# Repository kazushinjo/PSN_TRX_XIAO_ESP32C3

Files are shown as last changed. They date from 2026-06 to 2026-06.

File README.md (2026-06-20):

# PSN_TRX_XIAO_ESP32C3

Arduino Nano R4 + Seeed Studio XIAO ESP32C3 + Si5351 を使用した PSN 方式 SSB トランシーバー（KiCad 10.0）。

## 概要

50MHz 帯 PSN（位相シフト網）方式 SSB トランシーバー。VXO（水晶発振器）を
Si5351A クロックジェネレーターによる VFO に置き換え、Arduino Nano R4 でデジタル制御する。

Si5351 の CLK0（0°）/ CLK1（90°）二相出力を直接バランスドモジュレーターへ供給することで、
従来の RF PSN（LC 位相シフト回路）も不要となる。

## 主な仕様

| 項目 | 内容 |
|---|---|
| 周波数範囲 | 50.000 〜 51.000 MHz（6m バンド） |
| CLK0 出力 | 0° キャリア → C21（バランスドモジュレーター） |
| CLK1 出力 | 90° キャリア → C22（バランスドモジュレーター） |
| チューニングステップ | 10Hz / 100Hz / 1kHz / 10kHz / 100kHz |
| 表示 | OLED SSD1306 128×64 |
| 周波数記憶 | NVS（電源 OFF 後も保持） |

## ハードウェア構成

```
Arduino Nano R4
├── Seeed Studio XIAO ESP32C3 ─ サブコントローラ
├── Si5351A モジュール (AE-Si5351A) ─ I2C クロックジェネレーター
│   ├── CLK0（0°）  → バランスドモジュレーター C21
│   └── CLK1（90°） → バランスドモジュレーター C22
└── OLED / ロータリーエンコーダ 等

1W PA: RD06HVF1 (N-ch RF MOSFET) @ 12V, Class AB
```

## 1W パワーアンプ（Q8）

前段（2SC1815 等）の出力（約 20〜30mW）を増幅する終段アンプ。

| 項目 | 内容 |
|---|---|
| トランジスタ | **RD06HVF1**（三菱電機 N-ch RF MOSFET, 175MHz, 6W, TO-220F） |
| 電源電圧 | 12V |
| 動作クラス | Class AB |
| 静止電流 Idq | 200〜400mA（VR3 で調整） |
| 出力 | 約 1W @50MHz |
| 出力 LPF | 56pF → 270nH → 56pF（カットオフ約 60MHz） |

### バイアス回路

```
VCC(12V) → R22(470Ω) ─┬─ VR3(500Ω) → GND
                       │    ↓（ワイパー）
                       └── R21(10Ω) → Q8ゲート
```

- VR3 を中間位置でゲート電圧 ≈ **3.1V** → RD06HVF1 の Class AB 動作に最適
- VR3 を徐々に回してドレイン電流 (Idq) 200〜400mA に合わせる
- D3, D4（旧バイアスダイオード）は **0R ショート**（MOSFET では不要）
- R20（旧エミッタ抵抗 10Ω）は **0R ショート**（ソース直結 GND）

詳細は `docs/PSN_TRX_VFO改造仕様書.docx` を参照。

## KiCad ライブラリ状態

| ファイル | 状態 |
|---|---|
| `kicad/PSN_TRX.pretty/` | 全12フットプリント KiCad 10 形式 ✅ |
| `kicad/PSN_TRX.kicad_sym` | カスタムシンボル（RD06HVF1 含む）✅ |
| `kicad/fp-lib-table` | PSN_TRX ライブラリ登録済み ✅ |
| DRC ライブラリエラー | **0件** ✅ |

## ファイル構成

```
kicad/
  PSN_TRX.kicad_sch       - 回路図
  PSN_TRX.kicad_pcb       - PCB レイアウト（配線作業中）
  PSN_TRX.kicad_sym       - カスタムシンボルライブラリ
  PSN_TRX.pretty/         - カスタムフットプリントライブラリ（12点）
  BOM.md                  - 部品表（Markdown）
  bom.csv                 - 部品表（Shift-JIS CSV・入手先情報付き）
docs/
  PSN_TRX_VFO改造仕様書.docx  - 改造仕様書（部品リスト・回路図含む）
```

## 変更履歴

| 日付 | 変更内容 |
|---|---|
| 2026-06-20 | KiCad 回路図から bom.csv を新規生成（Shift-JIS）、入手先情報（秋月電子・サトー電気等）追加 |
| 2026-06-17 | Q3: 3SK59(TO-72 THT) → BF998(SOT-143 SMD)、カスタムシンボル・FP追加 |
| 2026-06-17 | Q8: 2SC1971 → RD06HVF1 (RF MOSFET) 換装、バイアス回路変更 |
| 2026-06-17 | KiCad 10 フットプリントライブラリ全面更新（12ファイル） |
| 2026-06-17 | U2: DIP-12 → DIP-8 フットプリント修正（AE-Si5351A 実寸合わせ） |

## ライセンス

MIT License

## 作者

JA3 (kazushinjo)

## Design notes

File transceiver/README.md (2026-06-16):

# PSN_TRX

PSN（位相シフト網）方式 SSB トランシーバの回路図プロジェクト（KiCad 10.0）。
50MHz 帯・VXO 制御。`PSN_TRX.kicad_sch` を手作業で作図中。

- リポジトリ: `kazushinjo/PSN_TRX_New`（Private）
- ローカル作業: `C:\Users\shinjo\OneDrive\デスクトップ\KiCad\PSN_TRX`

> ⚠️ **作業中** — まだ若干の回路追加が予定されています。追加完了後に続きの作業を進めます。

---

## リポジトリ構成

```
PSN_TRX/
├── PSN_TRX.kicad_sch          回路図本体
├── PSN_TRX.kicad_pro          プロジェクト設定
├── PSN_TRX.pretty/            自作フットプリント
│   ├── C_Trimmer_TMCV01.kicad_mod
│   ├── Transformer_ST71_CB19.kicad_mod
│   └── L_AL0510-153K_Vertical.kicad_mod
├── fp-lib-table               フットプリントライブラリ登録（${KIPRJMOD}/PSN_TRX.pretty）
├── *.py                       回路図生成・編集スクリプト（下記）
└── README.md
```

`*.kicad_prl` / `*.bak` / `*.lck` / `.history/` / `PSN_TRX-backups/` は `.gitignore` で除外。

---

## 主要コンポーネント（概算）

| 種別 | シンボル | 数 |
|---|---|---|
| 固定抵抗 | `Device:R` | 40 |
| 可変抵抗・ポット | `Device:R_Potentiometer` | 5 |
| コンデンサ | `Device:C` | 55 |
| トリマコンデンサ | `Device:C_Variable`（TC1, TC2） | 2 |
| ダイオード（1N60 ゲルマ検波） | `Device:D` | 6 |
| LED | `Device:LED` | 2 |
| トランス（7T50 等） | `Device:Transformer_1P_1S` | 9 |
| トランス（ST-71, CT付） | `Device:Transformer_1P_SS`（T1） | 1 |
| インダクタ | `Device:L`（L8 ほか） | — |
| トランジスタ | `Transistor_*` / `Device:Q_*` | 16 |
| OPアンプ | `Amplifier_Operational:LM2904`（NJM2904） | — |
| 水晶 | `Device:Crystal` | 1 |
| 三端子レギュレータ | `Regulator_Linear:MC78L05_TO92` | 1 |
| スイッチ | `Switch:SW_SPDT` / `SW_SPST` | 3 |

主要ブロックに「AF PSN・信号分割」セクション（ST-71 トランス T1 ＋ NJM2904 による音声位相分割）あり。

---

## フットプリント割り当て状況

### 割り当て済み ✅

| 部品 | フットプリント | 備考 |
|---|---|---|
| TC1 / TC2（トリマC 40p/5p） | `PSN_TRX:C_Trimmer_TMCV01` | Topmay TMCV01 |
| T1（ST-71 音声トランス） | `PSN_TRX:Transformer_ST71_CB19` | 山水 ST-71・CB-19 **リード型**・二次CT |
| L8（15mH インダクタ） | `PSN_TRX:L_AL0510-153K_Vertical` | AL0510-153K・**縦実装** |
| 固定抵抗 40個 | `Resistor_THT:R_Axial_DIN0207_L6.3mm_D2.5mm_P2.54mm_Vertical` | 1/4W・**縦実装** |
| ダイオード 6個（1N60） | `Diode_THT:D_DO-35_SOD27_P2.54mm_Vertical_CathodeUp` | DO-35・**縦実装** |

### 未割り当て ⏳
コンデンサ（55）／可変抵抗・ポット（5）／LED（2）／7T50系トランス（9）／トランジスタ（16）／OPアンプ／水晶／レギュレータ／スイッチ（3）

---

## 自作フットプリント（`PSN_TRX.pretty/`）

| 名称 | 内容 |
|---|---|
| `C_Trimmer_TMCV01` | Topmay TMCV01 セラミックトリマC（本体6×6mm, ピッチ5mm, ドリル1.2mm） |
| `Transformer_ST71_CB19` | 山水 ST-71（CB-19リード型）。pad 1,2=一次／3,4,5=二次（4=CT）。ピッチ I=8/G=14, 行間 C=16.5mm |
| `L_AL0510-153K_Vertical` | AL0510-153K 軸形インダクタ縦実装。本体D5×L14mm, リードピッチ P=2.54mm |

抵抗・ダイオードは KiCad 標準ライブラリ（`Resistor_THT` / `Diode_THT`、global fp-lib-table 登録済）を参照。

---

## スクリプト

| ファイル | 役割 |
|---|---|
| `generate_schematic.py` / `_v2.py` | 元 JPG 回路図からの初期生成（絶対座標配置） |
| `add_connections.py` / `add_wiring.py` | 配線追加 |
| `add_c13_c14.py` / `add_l4_l5.py` / `add_tc1_tc2.py` | 個別部品の追加 |
| `add_st71.py` | L8→T1 変換（reference/value/センタータップシンボル/FP 割当） |
| `set_vertical_footprints.py` | Device:R / Device:D へ縦実装FPを一括割当 |

> スクリプトは `.kicad_sch` を直接書き換えます。**実行前に KiCad を閉じる**こと。実行後は KiCad で開き直して確認。

---

## 残作業 / TODO

- [ ] 残りの回路を追加（予定）
- [ ] 未割り当て部品のフットプリント設定（C / 可変抵抗 / LED / 7T50トランス / トランジスタ / OPアンプ / 水晶 / レギュレータ / SW）
- [ ] ダイオードの向き（現状 CathodeUp）を回路に合わせて個別確認
- [ ] 抵抗サイズ（1/4W 前提）で 1/8W・1/2W があれば個別差し替え
- [ ] ERC / アノテーションの整理
- [ ] PCB レイアウト着手

---

## 環境・注意

- KiCad 10.0 / Windows 11
- ローカルが **OneDrive 配下**のため、git 同期と OneDrive 同期の競合（`.git` 内ロック等）に注意
- 配線は手動で実施

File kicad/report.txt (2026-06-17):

情報: シンボル 'L1:PSN_TRX:L_FCZ07S_CT' を処理中です。
情報: シンボル 'C1:Capacitor_THT:C_Disc_D5.0mm_W2.5mm_P2.50mm' を処理中です。
情報: シンボル 'C2:Capacitor_THT:C_Disc_D5.0mm_W2.5mm_P2.50mm' を処理中です。
情報: シンボル 'C3:Capacitor_THT:C_Disc_D5.0mm_W2.5mm_P2.50mm' を処理中です。
情報: シンボル 'C4:Capacitor_THT:C_Disc_D5.0mm_W2.5mm_P2.50mm' を処理中です。
情報: シンボル 'C5:Capacitor_THT:C_Disc_D5.0mm_W2.5mm_P2.50mm' を処理中です。
情報: シンボル 'C6:Capacitor_THT:C_Disc_D3.0mm_W1.6mm_P2.50mm' を処理中です。
情報: シンボル 'C7:Capacitor_THT:C_Disc_D5.0mm_W2.5mm_P2.50mm' を処理中です。
情報: シンボル 'C8:Capacitor_THT:C_Disc_D5.0mm_W2.5mm_P2.50mm' を処理中です。
情報: シンボル 'C9:Capacitor_THT:C_Disc_D5.0mm_W2.5mm_P2.50mm' を処理中です。
情報: シンボル 'C10:Capacitor_THT:C_Disc_D5.0mm_W2.5mm_P2.50mm' を処理中です。
情報: シンボル 'C11:Capacitor_THT:CP_Radial_D6.3mm_P2.50mm' を処理中です。
情報: シンボル 'C12:Capacitor_THT:C_Disc_D3.0mm_W1.6mm_P2.50mm' を処理中です。
情報: シンボル 'C13:Capacitor_THT:C_Disc_D5.0mm_W2.5mm_P2.50mm' を処理中です。
情報: シンボル 'C14:Capacitor_THT:C_Disc_D5.0mm_W2.5mm_P2.50mm' を処理中です。
情報: シンボル 'C15:Capacitor_THT:C_Disc_D5.0mm_W2.5mm_P2.50mm' を処理中です。
情報: シンボル 'C16:Capacitor_THT:CP_Radial_D6.3mm_P2.50mm' を処理中です。
情報: シンボル 'C17:Capacitor_THT:CP_Radial_D5.0mm_P2.00mm' を処理中です。
情報: シンボル 'C18:Capacitor_THT:CP_Radial_D5.0mm_P2.00mm' を処理中です。
情報: シンボル 'C19:Capacitor_THT:CP_Radial_D5.0mm_P2.00mm' を処理中です。
情報: シンボル 'C20:Capacitor_THT:CP_Radial_D5.0mm_P2.00mm' を処理中です。
情報: シンボル 'C21:Capacitor_THT:C_Disc_D5.0mm_W2.5mm_P2.50mm' を処理中です。
情報: シンボル 'C22:Capacitor_THT:C_Disc_D3.0mm_W1.6mm_P2.50mm' を処理中です。
情報: シンボル 'C23:Capacitor_THT:C_Disc_D5.0mm_W2.5mm_P2.50mm' を処理中です。
情報: シンボル 'C24:Capacitor_THT:C_Disc_D5.0mm_W2.5mm_P2.50mm' を処理中です。
情報: シンボル 'C25:Capacitor_THT:C_Disc_D5.0mm_W2.5mm_P2.50mm' を処理中です。
情報: シンボル 'C26:Capacitor_THT:C_Disc_D5.0mm_W2.5mm_P5.00mm' を処理中です。
情報: シンボル 'C27:Capacitor_THT:C_Disc_D5.0mm_W2.5mm_P5.00mm' を処理中です。
情報: シンボル 'C28:Capacitor_THT:C_Disc_D5.0mm_W2.5mm_P5.00mm' を処理中です。
情報: シンボル 'C29:Capacitor_THT:C_Disc_D5.0mm_W2.5mm_P5.00mm' を処理中です。
情報: シンボル 'C30:Capacitor_THT:C_Disc_D3.0mm_W1.6mm_P2.50mm' を処理中です。
情報: シンボル 'C31:Capacitor_THT:C_Disc_D5.0mm_W2.5mm_P5.00mm' を処理中です。
情報: シンボル 'C32:Capacitor_THT:C_Disc_D5.0mm_W2.5mm_P2.50mm' を処理中です。
情報: シンボル 'C33:Capacitor_THT:C_Disc_D5.0mm_W2.5mm_P2.50mm' を処理中です。
情報: シンボル 'C34:Capacitor_THT:C_Disc_D3.0mm_W1.6mm_P2.50mm' を処理中です。
情報: シンボル 'C35:Capacitor_THT:C_Disc_D5.0mm_W2.5mm_P2.50mm' を処理中です。
情報: シンボル 'C36:Capacitor_THT:C_Disc_D5.0mm_W2.5mm_P2.50mm' を処理中です。
情報: シンボル 'C37:Capacitor_THT:C_Disc_D3.0mm_W1.6mm_P2.50mm' を処理中です。
情報: シンボル 'C38:Capacitor_THT:C_Disc_D5.0mm_W2.5mm_P2.50mm' を処理中です。
情報: シンボル 'C39:Capacitor_THT:C_Disc_D5.0mm_W2.5mm_P2.50mm' を処理中です。
情報: シンボル 'C40:Capacitor_THT:C_Disc_D5.0mm_W2.5mm_P2.50mm' を処理中です。
情報: シンボル 'C41:Capacitor_THT:C_Disc_D5.0mm_W2.5mm_P2.50mm' を処理中です。
情報: シンボル 'C42:Capacitor_THT:C_Disc_D5.0mm_W2.5mm_P2.50mm' を処理中です。
情報: シンボル 'C43:Capacitor_THT:C_Disc_D3.0mm_W1.6mm_P2.50mm' を処理中です。
情報: シンボル 'C44:Capacitor_THT:C_Disc_D5.0mm_W2.5mm_P2.50mm' を処理中です。
情報: シンボル 'C45:Capacitor_THT:C_Disc_D5.0mm_W2.5mm_P2.50mm' を処理中です。
情報: シンボル 'C46:Capacitor_THT:C_Disc_D5.0mm_W2.5mm_P2.50mm' を処理中です。
情報: シンボル 'C47:Capacitor_THT:C_Disc_D5.0mm_W2.5mm_P2.50mm' を処理中です。
情報: シンボル 'C48:Capacitor_THT:C_Disc_D5.0mm_W2.5mm_P2.50mm' を処理中です。
情報: シンボル 'C49:Capacitor_THT:C_Disc_D5.0mm_W2.5mm_P2.50mm' を処理中です。
情報: シンボル 'C50:Capacitor_THT:CP_Radial_D5.0mm_P2.00mm' を処理中です。
情報: シンボル 'C51:Capacitor_THT:CP_Radial_D5.0mm_P2.00mm' を処理中です。
情報: シンボル 'C52:Capacitor_THT:CP_Radial_D5.0mm_P2.00mm' を処理中です。
情報: シンボル 'C53:Capacitor_THT:CP_Radial_D5.0mm_P2.00mm' を処理中です。
情報: シンボル 'C54:Capacitor_THT:CP_Radial_D5.0mm_P2.00mm' を処理中です。
情報: シンボル 'C55:Capacitor_THT:CP_Radial_D5.0mm_P2.00mm' を処理中です。
情報: シンボル 'C56:Capacitor_THT:CP_Radial_D5.0mm_P2.00mm' を処理中です。
情報: シンボル 'C57:Capacitor_THT:CP_Radial_D5.0mm_P2.00mm' を処理中です。
情報: シンボル 'C58:Capacitor_THT:CP_Radial_D5.0mm_P2.00mm' を処理中です。
情報: シンボル 'C59:Capacitor_THT:CP_Radial_D5.0mm_P2.00mm' を処理中です。
情報: シンボル 'C60:Capacitor_THT:CP_Radial_D5.0mm_P2.00mm' を処理中です。
情報: シンボル 'D1:Diode_THT:D_DO-35_SOD27_P2.54mm_Vertical_CathodeUp' を処理中です。
情報: シンボル 'D2:Diode_THT:D_DO-35_SOD27_P2.54mm_Vertical_CathodeUp' を処理中です。
情報: シンボル 'D3:Diode_THT:D_DO-35_SOD27_P7.62mm_Horizontal' を処理中です。
情報: シンボル 'D4:Diode_THT:D_DO-35_SOD27_P7.62mm_Horizontal' を処理中です。
情報: シンボル 'D5:Diode_THT:D_DO-35_SOD27_P2.54mm_Vertical_CathodeUp' を処理中です。
情報: シンボル 'D6:Diode_THT:D_DO-35_SOD27_P2.54mm_Vertical_CathodeUp' を処理中です。
情報: シンボル 'D7:Diode_THT:D_DO-35_SOD27_P2.54mm_Vertical_CathodeUp' を処理中です。
情報: シンボル 'D8:Diode_THT:D_DO-35_SOD27_P2.54mm_Vertical_CathodeUp' を処理中です。
情報: シンボル 'IC1:Package_TO_SOT_THT:TO-92_Inline' を処理中です。
情報: シンボル 'IC2:Package_DIP:DIP-8_W7.62mm' を処理中です。
情報: シンボル 'J1:Connector_PinHeader_2.54mm:PinHeader_1x02_P2.54mm_Vertical' を処理中です。
情報: シンボル 'J2:Connector_PinHeader_2.54mm:PinHeader_1x02_P2.54mm_Vertical' を処理中です。
情報: シンボル 'J3:Connector_PinHeader_2.54mm:PinHeader_1x02_P2.54mm_Vertical' を処理中です。
情報: シンボル 'J4:Connector_PinHeader_2.54mm:PinHeader_1x03_P2.54mm_Vertical' を処理中です。
情報: シンボル 'J5:Connector_PinHeader_2.54mm:PinHeader_1x03_P2.54mm_Vertical' を処理中です。
情報: シンボル 'J6:' を処理中です。
情報: シンボル 'J7:Connector_PinHeader_2.54mm:PinHeader_1x03_P2.54mm_Vertical' を処理中です。
情報: シンボル 'J8:Connector_PinHeader_2.54mm:PinHeader_1x02_P2.54mm_Vertical' を処理中です。
情報: シンボル 'K1:Relay_THT:Relay_DPDT_Omron_G5V-2' を処理中です。
情報: シンボル 'R22:Resistor_THT:R_Axial_DIN0207_L6.3mm_D2.5mm_P10.16mm_Horizontal' を処理中です。
情報: シンボル 'L2:PSN_TRX:L_FCZ07S_CT' を処理中です。
情報: シンボル 'L3:PSN_TRX:L_FCZ07S_CT' を処理中です。
情報: シンボル 'VR8:PSN_TRX:Potentiometer_TOCOS_GF063P_Vertical' を処理中です。
情報: シンボル 'L4:PSN_TRX:L_T50_2pin_Vertical' を処理中です。
情報: シンボル 'VR7:PSN_TRX:Potentiometer_TOCOS_GF063P_Vertical' を処理中です。
情報: シンボル 'L5:PSN_TRX:L_T50_2pin_Vertical' を処理中です。
情報: シンボル 'VR6:PSN_TRX:Potentiometer_TOCOS_GF063P_Vertical' を処理中です。
情報: シンボル 'L6:Inductor_THT:L_Axial_L9.5mm_D4.0mm_P12.70mm_Horizontal_Fastron_SMCC' を処理中です。
情報: シンボル 'L7:PSN_TRX:L_FCZ07S_CT' を処理中です。
情報: シンボル 'VR5:PSN_TRX:Potentiometer_TOCOS_GF063P_Vertical' を処理中です。
情報: シンボル 'L8:PSN_TRX:L_FCZ07S_CT' を処理中です。
情報: シンボル 'VR4:PSN_TRX:Potentiometer_TOCOS_GF063P_Vertical' を処理中です。
情報: シンボル 'VR3:Potentiometer_THT:Potentiometer_Bourns_3266W_Vertical' を処理中です。
情報: シンボル 'U2:PSN_TRX:DIP-8_W7.62mm' を処理中です。
情報: シンボル 'L9:PSN_TRX:L_FCZ07S_CT' を処理中です。
情報: シンボル 'U1:Package_TO_SOT_THT:TO-92_Inline' を処理中です。
情報: シンボル 'TC1:PSN_TRX:C_Trimmer_TMCV01' を処理中です。
情報: シンボル 'T1:PSN_TRX:Transformer_ST71_CB19' を処理中です。
情報: シンボル 'L10:PSN_TRX:L_AL0510-153K_Vertical' を処理中です。
情報: シンボル 'L11:PSN_TRX:L_AL0510-153K_Vertical' を処理中です。
情報: シンボル 'RFC1:Inductor_THT:L_Axial_L9.5mm_D4.0mm_P12.70mm_Horizontal_Fastron_SMCC' を処理中です。
情報: シンボル 'R41:Resistor_THT:R_Axial_DIN0207_L6.3mm_D2.5mm_P2.54mm_Vertical' を処理中です。
情報: シンボル 'R40:Resistor_THT:R_Axial_DIN0207_L6.3mm_D2.5mm_P2.54mm_Vertical' を処理中です。
情報: シンボル 'R39:Resistor_THT:R_Axial_DIN0207_L6.3mm_D2.5mm_P2.54mm_Vertical' を処理中です。
情報: シンボル 'R38:Resistor_THT:R_Axial_DIN0207_L6.3mm_D2.5mm_P2.54mm_Vertical' を処理中です。
情報: シンボル 'R37:Resistor_THT:R_Axial_DIN0207_L6.3mm_D2.5mm_P2.54mm_Vertical' を処理中です。
情報: シンボル 'L12:PSN_TRX:L_AL0510-153K_Vertical' を処理中です。
情報: シンボル 'R36:Resistor_THT:R_Axial_DIN0207_L6.3mm_D2.5mm_P2.54mm_Vertical' を処理中です。
情報: シンボル 'R35:Resistor_THT:R_Axial_DIN0207_L6.3mm_D2.5mm_P2.54mm_Vertical' を処理中です。
情報: シンボル 'A1:PSN_TRX:Seeeduino_XIAO_Socket' を処理中です。
情報: シンボル 'R34:Resistor_THT:R_Axial_DIN0207_L6.3mm_D2.5mm_P2.54mm_Vertical' を処理中です。
情報: シンボル 'R33:Resistor_THT:R_Axial_DIN0207_L6.3mm_D2.5mm_P2.54mm_Vertical' を処理中です。
情報: シンボル 'R32:Resistor_THT:R_Axial_DIN0207_L6.3mm_D2.5mm_P2.54mm_Vertical' を処理中です。
情報: シンボル 'L13:PSN_TRX:L_AL0510-153K_Vertical' を処理中です。
情報: シンボル 'R31:Resistor_THT:R_Axial_DIN0207_L6.3mm_D2.5mm_P2.54mm_Vertical' を処理中です。
情報: シンボル 'R30:Resistor_THT:R_Axial_DIN0207_L6.3mm_D2.5mm_P2.54mm_Vertical' を処理中です。
情報: シンボル 'R29:Resistor_THT:R_Axial_DIN0207_L6.3mm_D2.5mm_P2.54mm_Vertical' を処理中です。
情報: シンボル 'R28:Resistor_THT:R_Axial_DIN0207_L6.3mm_D2.5mm_P2.54mm_Vertical' を処理中です。
情報: シンボル 'R27:Resistor_THT:R_Axial_DIN0207_L6.3mm_D2.5mm_P2.54mm_Vertical' を処理中です。
情報: シンボル 'R26:Resistor_THT:R_Axial_DIN0207_L6.3mm_D2.5mm_P2.54mm_Vertical' を処理中です。
情報: シンボル 'L14:PSN_TRX:L_AL0510-153K_Vertical' を処理中です。
情報: シンボル 'R25:Resistor_THT:R_Axial_DIN0207_L6.3mm_D2.5mm_P2.54mm_Vertical' を処理中です。
情報: シンボル 'R24:Resistor_THT:R_Axial_DIN0207_L6.3mm_D2.5mm_P2.54mm_Vertical' を処理中です。
情報: シンボル 'R23:Resistor_THT:R_Axial_DIN0207_L6.3mm_D2.5mm_P2.54mm_Vertical' を処理中です。
情報: シンボル 'LED2:Connector_PinHeader_2.54mm:PinHeader_1x02_P2.54mm_Vertical' を処理中です。
情報: シンボル 'Q1:Package_TO_SOT_THT:TO-92_Inline' を処理中です。
情報: シンボル 'Q2:Package_TO_SOT_THT:TO-92_Inline' を処理中です。
情報: シンボル 'Q3:Package_TO_SOT_THT:TO-72-4' を処理中です。
情報: シンボル 'Q4:Package_TO_SOT_THT:TO-92_Inline' を処理中です。
情報: シンボル 'Q5:Package_TO_SOT_THT:TO-92_Inline' を処理中です。
情報: シンボル 'Q6:Package_TO_SOT_THT:TO-92_Inline' を処理中です。
情報: シンボル 'Q7:Package_TO_SOT_THT:TO-92_Inline' を処理中です。
情報: シンボル 'Q8:Package_TO_SOT_THT:TO-220-3_Vertical' を処理中です。
情報: シンボル 'Q9:Package_TO_SOT_THT:TO-92_Inline' を処理中です。
情報: シンボル 'Q10:Package_TO_SOT_THT:TO-92_Inline' を処理中です。
情報: シンボル 'Q11:Package_TO_SOT_THT:TO-92_Inline' を処理中です。
情報: シンボル 'Q12:Package_TO_SOT_THT:TO-92_Inline' を処理中です。
情報: シンボル 'Q13:Package_TO_SOT_THT:TO-92_Inline' を処理中です。
情報: シンボル 'Q14:Package_TO_SOT_THT:TO-92_Inline' を処理中です。
情報: シンボル 'R1:Resistor_THT:R_Axial_DIN0207_L6.3mm_D2.5mm_P2.54mm_Vertical' を処理中です。
情報: シンボル 'R2:Resistor_THT:R_Axial_DIN0207_L6.3mm_D2.5mm_P2.54mm_Vertical' を処理中です。
情報: シンボル 'R3:Resistor_THT:R_Axial_DIN0207_L6.3mm_D2.5mm_P2.54mm_Vertical' を処理中です。
情報: シンボル 'R4:Resistor_THT:R_Axial_DIN0207_L6.3mm_D2.5mm_P2.54mm_Vertical' を処理中です。
情報: シンボル 'R5:Resistor_THT:R_Axial_DIN0207_L6.3mm_D2.5mm_P2.54mm_Vertical' を処理中です。
情報: シンボル 'R6:Resistor_THT:R_Axial_DIN0207_L6.3mm_D2.5mm_P2.54mm_Vertical' を処理中です。
情報: シンボル 'R7:Resistor_THT:R_Axial_DIN0207_L6.3mm_D2.5mm_P2.54mm_Vertical' を処理中です。
情報: シンボル 'R8:Resistor_THT:R_Axial_DIN0207_L6.3mm_D2.5mm_P2.54mm_Vertical' を処理中です。
情報: シンボル 'R9:Resistor_THT:R_Axial_DIN0207_L6.3mm_D2.5mm_P2.54mm_Vertical' を処理中です。
情報: シンボル 'R10:Resistor_THT:R_Axial_DIN0207_L6.3mm_D2.5mm_P2.54mm_Vertical' を処理中です。
情報: シンボル 'R11:Resistor_THT:R_Axial_DIN0207_L6.3mm_D2.5mm_P2.54mm_Vertical' を処理中です。
情報: シンボル 'R12:Resistor_THT:R_Axial_DIN0207_L6.3mm_D2.5mm_P2.54mm_Vertical' を処理中です。
情報: シンボル 'R13:Resistor_THT:R_Axial_DIN0207_L6.3mm_D2.5mm_P2.54mm_Vertical' を処理中です。
情報: シンボル 'R14:Resistor_THT:R_Axial_DIN0207_L6.3mm_D2.5mm_P2.54mm_Vertical' を処理中です。
情報: シンボル 'R15:Resistor_THT:R_Axial_DIN0207_L6.3mm_D2.5mm_P2.54mm_Vertical' を処理中です。
情報: シンボル 'R17:Resistor_THT:R_Axial_DIN0207_L6.3mm_D2.5mm_P2.54mm_Vertical' を処理中です。
情報: シンボル 'R18:Resistor_THT:R_Axial_DIN0207_L6.3mm_D2.5mm_P2.54mm_Vertical' を処理中です。
情報: シンボル 'R19:Resistor_THT:R_Axial_DIN0207_L6.3mm_D2.5mm_P2.54mm_Vertical' を処理中です。
情報: シンボル 'R20:Resistor_THT:R_Axial_DIN0207_L6.3mm_D2.5mm_P10.16mm_Horizontal' を処理中です。
情報: シンボル 'R21:Resistor_THT:R_Axial_DIN0207_L6.3mm_D2.5mm_P10.16mm_Horizontal' を処理中です。
未使用のネット unconnected-(U1-VDDO-Pad1)_1 を削除します。
L14 に製造属性 'DNP(未実装)' を追加しました。
L14 の製造属性 'DNP(未実装)' を削除しました。
未使用のネット unconnected-(U1-VDDO-Pad1) を削除します。
L13 に製造属性 'DNP(未実装)' を追加しました。
未使用のネット unconnected-(L6-CT-Pad2) を削除します。
未使用のネット Net-(L6-SA) を削除します。
未使用のネット Net-(L6-AA) を削除します。
L13 の製造属性 'DNP(未実装)' を削除しました。
未使用のネット Net-(L13-SA) を削除します。
L12 に製造属性 'DNP(未実装)' を追加しました。
未使用のネット Net-(L12-SA) を削除します。
未使用のネット unconnected-(U1-CLK2-Pad7) を削除します。
L12 の製造属性 'DNP(未実装)' を削除しました。
未使用のネット Net-(J5-SDA) を削除します。
L11 に製造属性 'DNP(未実装)' を追加しました。
未使用のネット Net-(J5-SCL) を削除します。
未使用のネット Net-(D4-A) を削除します。
未使用のネット Net-(C22-Pad2) を削除します。
L11 の製造属性 'DNP(未実装)' を削除しました。
未使用のネット Net-(C22-Pad1) を削除します。
L9 に製造属性 'DNP(未実装)' を追加しました。
L9 の製造属性 'DNP(未実装)' を削除しました。
L8 の製造属性 'DNP(未実装)' を削除しました。
U2 に製造属性 'DNP(未実装)' を追加しました。
L8 に製造属性 'DNP(未実装)' を追加しました。
U2 の製造属性 'DNP(未実装)' を削除しました。
警告: コンポーネント U2 パッド 11 に対するネットが見つかりません（ピン 11 がシンボルにありません）。
警告: コンポーネント U2 パッド 10 に対するネットが見つかりません（ピン 10 がシンボルにありません）。
警告: コンポーネント U2 パッド 9 に対するネットが見つかりません（ピン 9 がシンボルにありません）。
警告: コンポーネント L12 パッド 4 に対するネットが見つかりません（ピン 4 がシンボルにありません）。
警告: コンポーネント U2 パッド 12 に対するネットが見つかりません（ピン 12 がシンボルにありません）。
警告: コンポーネント L13 パッド 5 に対するネットが見つかりません（ピン 5 がシンボルにありません）。
警告: コンポーネント L13 パッド 3 に対するネットが見つかりません（ピン 3 がシンボルにありません）。
警告: コンポーネント L13 パッド 4 に対するネットが見つかりません（ピン 4 がシンボルにありません）。
警告: コンポーネント L12 パッド 3 に対するネットが見つかりません（ピン 3 がシンボルにありません）。
警告: コンポーネント L11 パッド 4 に対するネットが見つかりません（ピン 4 がシンボルにありません）。
警告: コンポーネント L11 パッド 5 に対するネットが見つかりません（ピン 5 がシンボルにありません）。
警告: コンポーネント L11 パッド 3 に対するネットが見つかりません（ピン 3 がシンボルにありません）。
警告: コンポーネント L12 パッド 5 に対するネットが見つかりません（ピン 5 がシンボルにありません）。
エラー: J6 パッド 4 が Connector_PinHeader_2.54mm:PinHeader_1x03_P2.54mm_Vertical に見つかりません。
エラー: L8 パッド 5 が PSN_TRX:L_AL0510-153K_Vertical に見つかりません。
エラー: L8 パッド 3 が PSN_TRX:L_AL0510-153K_Vertical に見つかりません。
エラー: L8 パッド 4 が PSN_TRX:L_AL0510-153K_Vertical に見つかりません。
エラー: VR8 を追加できません(フットプリント "PSN_TRX:Potentiometer_TOCOS_GF063P_Vertical" が見つかりません)。
エラー: L9 パッド 3 が PSN_TRX:L_AL0510-153K_Vertical に見つかりません。
エラー: L9 パッド 4 が PSN_TRX:L_AL0510-153K_Vertical に見つかりません。
エラー: L11 を更新できません(フットプリント "PSN_TRX:L_AL0510-153K_Vertical" が見つかりません)。
エラー: L3 を追加できません(フットプリント "PSN_TRX:L_FCZ07S_CT" が見つかりません)。
エラー: L4 を追加できません(フットプリント "PSN_TRX:L_T50_2pin_Vertical" が見つかりません)。
エラー: L5 を追加できません(フットプリント "PSN_TRX:L_T50_2pin_Vertical" が見つかりません)。
エラー: L12 を更新できません(フットプリント "PSN_TRX:L_AL0510-153K_Vertical" が見つかりません)。
エラー: L7 を追加できません(フットプリント "PSN_TRX:L_FCZ07S_CT" が見つかりません)。
エラー: L13 を更新できません(フットプリント "PSN_TRX:L_AL0510-153K_Vertical" が見つかりません)。
エラー: L8 を更新できません(フットプリント "PSN_TRX:L_FCZ07S_CT" が見つかりません)。
エラー: TC1 を追加できません(フットプリント "PSN_TRX:C_Trimmer_TMCV01" が見つかりません)。
エラー: L9 を更新できません(フットプリント "PSN_TRX:L_FCZ07S_CT" が見つかりません)。
エラー: U2 を更新できません(フットプリント "PSN_TRX:DIP-8_W7.62mm" が見つかりません)。
エラー: L14 を更新できません(フットプリント "PSN_TRX:L_AL0510-153K_Vertical" が見つかりません)。
エラー: L9 パッド 5 が PSN_TRX:L_AL0510-153K_Vertical に見つかりません。

情報: 合計警告数: 13、エラー数: 20.

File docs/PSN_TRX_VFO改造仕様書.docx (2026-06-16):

# PSN_TRX VFO 改造仕様書

PSN方式SSBトランシーバー VXO→Arduino Nano R4+Si5351 VFO 置き換え

作成日：2026年6月15日

# 1. 改造概要

既存のVXO（水晶発振器）およびRF PSNパッシブ回路を、Arduino Nano R4マイコンとSi5351クロックジェネレーターを使ったVFOに置き換える。

Si5351はCLK0（0°）とCLK1（90°）の2系統出力を持ち、これを直接バランスドモジュレーターのキャリア入力へ供給することで、従来のRF PSN（LC位相シフト網）も不要となる。

# 2. 変更前後の比較

項目 | 変更前（VXO） | 変更後（Arduino Nano R4+Si5351）
発振方式 | 水晶発振（50.5MHz 固定） | Si5351 PLL（50.000〜51.000MHz 可変）
キャリア位相分割 | RF PSN パッシブLC回路 | Si5351 CLK0/CLK1（0°/90° 同時出力）
周波数調整 | バリコン（VC1）による微調のみ | ロータリーエンコーダで自由に設定
周波数表示 | なし | OLED 128×64 表示
周波数記憶 | なし | EEPROM（電源OFF後も保持）
チューニングステップ | なし | 10Hz/100Hz/1kHz/10kHz/100kHz
90°精度 | 設計周波数のみ正確 | 全周波数域で正確

# 3. 削除する部品

以下の部品はVFO置き換えにより不要となり、基板から削除する。

## 3.1 VXO回路

部品番号 | 種別 | 備考
Q7 | 2SC1923 | VXO 発振トランジスタ
Q8 | 2SC1923 | VXO バッファトランジスタ
X1 | 50.5MHz 水晶 | 3次倍音水晶
L3 | 7T5 トランス | VXO 出力トランス
L4 | T-30-10 コイル | VXO タンク回路
L5 | T-30-10 コイル | VXO タンク回路
TC1 | トリマコンデンサ | 発振周波数調整
TC2 | トリマコンデンサ | 発振周波数調整
VC1 | 30pF バリコン | 周波数可変用
C9 | 100pF | バイパスコンデンサ
C10 | 100pF | タンク回路
C11 | 47pF | タンク回路
C12 | 47pF | タンク回路
C13 | 5pF | タンク回路
C14 | 47pF | タンク回路
C115 | 0.01μF | バイパスコンデンサ
R17 | 100kΩ | バイアス抵抗
R18 | 1kΩ | バイアス抵抗
R21 | 220kΩ | バイアス抵抗
J5 | FREQ-VCコネクタ | 周波数コントロール端子

## 3.2 RF PSN回路（LC位相シフト網）

Si5351のCLK0/CLK1が直接0°/90°キャリアを供給するため、RF PSNパッシブ回路は不要。

（対象部品は回路図上のRF PSNセクションのLC素子群）

# 4. 追加する部品

部品 | 仕様 | 個数 | 備考
Arduino Nano R4 DevKit | Arduino Nano R4-WROOM-32等 | 1 | I2C/GPIO使用
Si5351A モジュール | 25MHz基準水晶 | 1 | I2C接続（0x60）
OLED | SSD1306 128×64 I2C | 1 | I2C接続（0x3C）
ロータリーエンコーダ | プッシュSW付き | 1 | チューニング・ステップ切替
チップインダクタ | 100nH | 2 | LPF用（CLK0/CLK1各1個）
チップコンデンサ | 47pF NPO | 4 | LPF用（各2個）
抵抗 | 470Ω | 2 | レベル調整分圧用
抵抗 | 47Ω | 2 | レベル調整分圧用

# 5. 接続図

## 5.1 Arduino Nano R4 ピン配置

Arduino Nano R4 GPIO | 接続先 | 備考
A4 (SDA) | Si5351 SDA / OLED SDA | I2C共通バス
A5 (SCL) | Si5351 SCL / OLED SCL | I2C共通バス
D2 | ロータリーエンコーダ A相
D3 | ロータリーエンコーダ B相
D4 | ロータリーエンコーダ SW | プッシュボタン
3.3V | Si5351 VCC / OLED VCC
GND | Si5351 GND / OLED GND

## 5.2 Si5351 → PSN回路 接続（LPF・レベル調整含む）

Si5351 π型LPF レベル調整 PSN回路

CLK0(0°) ─┬─ 100nH ─┬─── 470Ω ─┬──── C21入力（0°キャリア）
│ │ 47Ω
47pF 47pF │
│ │ GND
GND GND

CLK1(90°) ─┬─ 100nH ─┬─── 470Ω ─┬──── C22入力（90°キャリア）
│ │ 47Ω
47pF 47pF │
│ │ GND
GND GND

# 6. LPFおよびレベル調整

## 6.1 LPF（ローパスフィルター）の必要性

Si5351はCMOS矩形波を出力するため、高調波成分が含まれる。アマチュア無線規定では不要輻射を基本波より40dB以上抑圧する必要があるため、LPFを挿入する。

周波数 | 内容 | LPF後の減衰
50〜51MHz | 基本波（使用周波数） | < 1dB（ほぼ通過）
150〜153MHz | 第3高調波 | 約 −30dB
250〜255MHz | 第5高調波 | 約 −50dB

## 6.2 レベル調整の必要性

Si5351出力は約3.3V（CMOS）であるが、バランスドモジュレーターに必要なキャリアレベルは0.3〜0.5Vピーク程度である。470Ω＋47Ωの分圧回路で約1/11（−20dB）に減衰させる。

バランスドモジュレーター | 必要レベル | 備考
D1〜D4（1N60 ダイオードリング） | 0.3〜0.5V ピーク | Ge ダイオード Vf≈0.2〜0.3V
Q9/Q10（2SK439 MOSFET） | 0.3〜1V ピーク | ゲート入力（高インピーダンス）

※ 試作時は470Ωをトリマポテンショメーター（500Ω）に置き換え、VR4/VR5のキャリアバランスと合わせて最適値を調整すること。

# 7. ソフトウェア

## 7.1 開発環境

項目 | 内容
IDE | Arduino IDE
ボード | Arduino Nano R4 Dev Module
スケッチファイル | PSN_VFO/PSN_VFO.ino

## 7.2 必要ライブラリ（Arduino IDEライブラリマネージャーでインストール）

ライブラリ名 | 作者 | 用途
Etherkit Si5351 | Jason Milldrum | Si5351制御
Adafruit SSD1306 | Adafruit | OLED表示
Adafruit GFX Library | Adafruit | グラフィック基盤

## 7.3 主要機能

機能 | 内容
周波数範囲 | 50.000〜51.000 MHz
CLK0出力 | 0°キャリア → C21へ
CLK1出力 | 90°キャリア → C22へ
PLL方式 | PLL A 整数分周（÷16）：50MHz×16=800MHz
90°精度 | 位相レジスタによる高精度（全周波数域で一定）
チューニングステップ | 10Hz / 100Hz / 1kHz / 10kHz / 100kHz（ボタン切替）
周波数記憶 | EEPROM（不揮発メモリ）に自動保存
OLED表示 | 周波数・ステップ・バンド名表示

# 8. 注意事項

- Si5351モジュールの基準水晶が25MHz以外（27MHz等）の場合、スケッチ内の si5351.init() の第2引数を変更すること。
- CLK0とCLK1は必ず同一PLL（PLL A）を使用し、整数分周にすること（スケッチでは÷16固定）。
- レベル調整抵抗値は試作時にトリマポテンショメーターで最適化し、確定後に固定抵抗に置き換えること。
- C21/C22の値（現状：C21=0.001μF）はカップリングコンデンサとして機能するが、LPF後の正弦波キャリアを正しく通過させることを実測で確認すること。
- TX時の最終段フィルターと合わせて高調波抑圧量を確認すること。

以上

# 9. 1W パワーアンプ（PA）追加

既存の終段増幅（Q15: 2SC1815）では50MHzで10〜30mW程度の出力しか得られないため、2SC1971を使用した1W PAを後段に追加する。

## 9.1 使用トランジスタ：2SC1971

パラメータ | 値 | 備考
Vceo | 40V
Ic max | 1.5A
最大消費電力 Pt | 7W | ヒートシンク必要
遷移周波数 ft | 175MHz | 50MHzで十分な利得
50MHz 出力（Vcc=12V） | 約1〜1.5W | 入力80mW時
電力利得（50MHz） | 約11dB | 80mW入力→1W出力

※ 既存TX出力（10〜30mW）から1Wを得るには利得が若干不足するため、既存の励振段（Q12）の出力を最大化するか、中間にプリドライバーを追加することを推奨する。

## 9.2 回路図（2SC1971 クラスAB PA）

+12V
│
RFC1
(10μH)
│
┌── 0.1μF ─┴─ 1000pF ──┐
│ (バイパス) (バイパス) │
GND GND
│
Collector
[2SC1971]
Emitter
│
R5 10Ω ← エミッタ抵抗（安定化）
│
GND

既存TX出力 Base
│ │
C1(100pF) ── L1(47nH) ──────┤
│ │
C2(22pF) R4(10Ω) ← ベース安定化抵抗
│ │
GND バイアス回路

バイアス回路:
+12V ── R1(470Ω) ── VR1(500Ω) ──┬── Base
│
D1(1N4148)
D2(1N4148) ← 温度補償
│
GND

Collector ── C3(100pF) ── [出力LPF] ── ANT(50Ω)
(DCカット)

## 9.3 入力整合回路（L型）

2SC1971の入力インピーダンスは50MHzで約3〜5Ω。既存回路出力（50Ω系）との整合をL型ネットワークで行う。

既存TX出力(50Ω) ── C1(100pF) ── L1(47nH) ──── Base
│
C2(22pF)
│
GND

L1 = 47nH (設計値: Q=3, Rin=5Ω, f=50MHz)
C2 = 22pF (整合用シャントコンデンサ)

## 9.4 出力ローパスフィルター（必須）

PA出力の高調波を抑圧するためLPFを挿入する。カットオフ約60MHz、3素子Butterworth型。

Collector ── C3(100pF) ──┬── L2(270nH) ──┬── ANT(50Ω)
(DCカット) │ │
C4(56pF) C5(56pF)
│ │
GND GND

C4 = C5 = 56pF (NPO)
L2 = 270nH
カットオフ: 約60MHz
150MHz(第3高調波)での減衰: 約 -30dB

## 9.5 追加部品リスト（PA）

記号 | 部品 | 値/型番 | 個数 | 備考
Q16 | RFトランジスタ | 2SC1971 | 1 | ヒートシンク取付
RFC1 | RFチョーク | 10μH | 1 | コレクタ電源デカップリング
L1 | チップインダクタ | 47nH | 1 | 入力整合
L2 | コイル | 270nH | 1 | 出力LPF（T-50コア巻線可）
C1 | コンデンサ | 100pF NPO | 1 | 入力カップリング
C2 | コンデンサ | 22pF NPO | 1 | 入力整合シャント
C3 | コンデンサ | 100pF NPO | 1 | 出力DCカット
C4, C5 | コンデンサ | 56pF NPO | 2 | 出力LPF
C_bp1 | コンデンサ | 0.1μF | 1 | 電源バイパス
C_bp2 | コンデンサ | 1000pF | 1 | 電源バイパス(RF)
R1 | 抵抗 | 470Ω | 1 | バイアス電流制限
VR1 | トリマポット | 500Ω | 1 | アイドル電流調整
R4 | 抵抗 | 10Ω | 1 | ベース安定化
R5 | 抵抗 | 10Ω | 1 | エミッタ抵抗
D1, D2 | ダイオード | 1N4148 | 2 | 温度補償バイアス
ヒートシンク | 放熱板 | 小型 | 1 | 2SC1971取付用

## 9.6 バイアス調整手順

1. アンテナを50Ω ダミーロードに接続する。
2. VR1（トリマポット）を最大抵抗値（バイアス最小）にセットしてから電源を入れる。
3. 電源電流計を見ながらVR1を徐々に調整し、アイドル電流が約50〜80mA になるようにセットする（クラスAB）。
4. 既存TXから送信し、出力計でPA出力を確認する。
5. アイドル電流を変えて最大出力・最小歪みのポイントを探す。
6. 発振や不安定な動作が見られる場合はR4（ベース抵抗）を22〜47Ωに増やす。

## 9.7 完成後の送信信号経路

マイク
│
AF PSN（音声位相シフト: 0°/90°）
│
合成・平衡変調（D1〜D4 ダイオードリング）
│ ← Si5351 CLK0(0°)/CLK1(90°) キャリア注入
励振増幅（Q12: 2SC1815）
│
終段増幅（Q15: 2SC1815） ← 約20〜30mW
│
【追加】1W PA（Q16: 2SC1971） ← 約1W
│
出力LPF（C4/C5/L2）
│
アンテナ（50Ω）

以上（9章追記）

# Arduino Nano R4 移植 & KiCad ライブラリ統合

## 1. Arduino Nano R4 への移植概要

PSN_TRX_Arduino Nano R4 プロジェクトを Arduino Nano R4（ルネサス RA4M1 ベース）に移植しました。

主な変更：

- マイコン: Arduino Nano R4 → Arduino Nano R4 (Renesas RA4M1, 48MHz)
- パッケージ: DIP 30 ピン（前世代 Nano との互換性あり）
- ストレージ: EEPROM (EEPROM) → EEPROM
- I2C ピン: A4 (SDA), A5 (SCL) に固定

## 2. GPIO ピン配置変更

Arduino Nano R4 から Arduino Nano R4 への変更:

機能 | Arduino Nano R4 | Nano R4
I2C SDA | A4 | A4
I2C SCL | A5 | A5
エンコーダ A | D2 | D2
エンコーダ B | D3 | D3
エンコーダ SW | D4 | D4

## 3. KiCad シンボル・フットプリント

### 3.1 Arduino Nano R4 (DIP 30)

シンボル: Arduino_Nano_R4.kicad_sym
フットプリント: Arduino_Nano_R4_Socket.kicad_mod
パッケージ: DIP 30 ピン、スルーホール

- ピン機能:
- D0-D13: デジタル I/O (14 ピン)
- A0-A7: アナログ入力 (8 ピン)
- 5V, 3.3V, GND: 電源

### 3.2 Si5351A QFN-20

シンボル: Si5351A.kicad_sym
フットプリント: Si5351A_QFN-20.kicad_mod
パッケージ: QFN-20 (4x4mm, 0.5mm ピッチ)

- ピン機能:
- CLK0-CLK3: クロック出力 (4 チャネル)
- SDA/SCL: I2C インターフェース
- XA/XB: クリスタル接続
- VDDA/VCCIO: 電源

### 3.3 Si5351 DIP-8 モジュール

シンボル: Si5351_DIP8.kicad_sym (1.5倍拡大)
フットプリント: DIP-8_W7.62mm.kicad_mod
パッケージ: DIP-8 (7.62mm ピッチ)

ピン配置:

ピン番号 | 機能
1 | VDDO - 出力バッファ用電源
2 | SCL - I2C クロック入力
3 | SDA - I2C データ入出力
4 | GND - グラウンド

ピン配置（続き）:

ピン番号 | 機能
5 | CLK0 - クロック出力 1
6 | CLK1 - クロック出力 2
7 | CLK2 - クロック出力 3
8 | VDD - コア電源入力

## 4. KiCad ライブラリ統合

sym-lib-table（シンボルライブラリ）に以下を登録:

- PSN_TRX - プロジェクト用カスタムシンボル
- Arduino_Nano_R4 - Arduino Nano R4 シンボル
- Si5351A - Si5351A QFN-20 シンボル
- Si5351_DIP8 - Si5351 DIP-8 モジュールシンボル
- Arduino - Arduino 公式ボードライブラリ

fp-lib-table（フットプリントライブラリ）に以下を登録:

- PSN_TRX.pretty - プロジェクト用フットプリント
- Arduino - Arduino 公式フットプリント

## 5. 作成・更新ファイル一覧

シンボルファイル:

- Arduino_Nano_R4.kicad_sym (7.2 KB)
- Si5351A.kicad_sym (5.2 KB)
- Si5351_DIP8.kicad_sym (2.8 KB)

フットプリントファイル:

- Arduino_Nano_R4_Socket.kicad_mod (4.4 KB)
- Si5351A_QFN-20.kicad_mod (3.0 KB)
- DIP-8_W7.62mm.kicad_mod (2.0 KB)

# Arduino Nano R4 移植 & KiCad ライブラリ統合

## 1. Arduino Nano R4 への移植概要

PSN_TRX_Arduino Nano R4 プロジェクトを Arduino Nano R4（ルネサス RA4M1 ベース）に移植しました。

主な変更：

- マイコン: Arduino Nano R4 → Arduino Nano R4 (Renesas RA4M1, 48MHz)
- パッケージ: DIP 30 ピン（前世代 Nano との互換性あり）
- ストレージ: EEPROM (EEPROM) → EEPROM
- I2C ピン: A4 (SDA), A5 (SCL) に固定

## 2. GPIO ピン配置変更

Arduino Nano R4 から Arduino Nano R4 への変更:

機能 | Arduino Nano R4 | Nano R4
I2C SDA | A4 | A4
I2C SCL | A5 | A5
エンコーダ A | D2 | D2
エンコーダ B | D3 | D3
エンコーダ SW | D4 | D4

## 3. KiCad シンボル・フットプリント

### 3.1 Arduino Nano R4 (DIP 30)

シンボル: Arduino_Nano_R4.kicad_sym
フットプリント: Arduino_Nano_R4_Socket.kicad_mod
パッケージ: DIP 30 ピン、スルーホール

- ピン機能:
- D0-D13: デジタル I/O (14 ピン)
- A0-A7: アナログ入力 (8 ピン)
- 5V, 3.3V, GND: 電源

### 3.2 Si5351A QFN-20

シンボル: Si5351A.kicad_sym
フットプリント: Si5351A_QFN-20.kicad_mod
パッケージ: QFN-20 (4x4mm, 0.5mm ピッチ)

- ピン機能:
- CLK0-CLK3: クロック出力 (4 チャネル)
- SDA/SCL: I2C インターフェース
- XA/XB: クリスタル接続
- VDDA/VCCIO: 電源

### 3.3 Si5351 DIP-8 モジュール

シンボル: Si5351_DIP8.kicad_sym (1.5倍拡大)
フットプリント: DIP-8_W7.62mm.kicad_mod
パッケージ: DIP-8 (7.62mm ピッチ)

ピン配置:

ピン番号 | 機能
1 | VDDO - 出力バッファ用電源
2 | SCL - I2C クロック入力
3 | SDA - I2C データ入出力
4 | GND - グラウンド

ピン配置（続き）:

ピン番号 | 機能
5 | CLK0 - クロック出力 1
6 | CLK1 - クロック出力 2
7 | CLK2 - クロック出力 3
8 | VDD - コア電源入力

## 4. KiCad ライブラリ統合

sym-lib-table（シンボルライブラリ）に以下を登録:

- PSN_TRX - プロジェクト用カスタムシンボル
- Arduino_Nano_R4 - Arduino Nano R4 シンボル
- Si5351A - Si5351A QFN-20 シンボル
- Si5351_DIP8 - Si5351 DIP-8 モジュールシンボル
- Arduino - Arduino 公式ボードライブラリ

fp-lib-table（フットプリントライブラリ）に以下を登録:

- PSN_TRX.pretty - プロジェクト用フットプリント
- Arduino - Arduino 公式フットプリント

## 5. 作成・更新ファイル一覧

シンボルファイル:

- Arduino_Nano_R4.kicad_sym (7.2 KB)
- Si5351A.kicad_sym (5.2 KB)
- Si5351_DIP8.kicad_sym (2.8 KB)

フットプリントファイル:

- Arduino_Nano_R4_Socket.kicad_mod (4.4 KB)
- Si5351A_QFN-20.kicad_mod (3.0 KB)
- DIP-8_W7.62mm.kicad_mod (2.0 KB)

## 6. VXO（可変周波数発振子）回路

PSN TRX の周波数設定用に、バリキャップダイオードを使用した 2 系統の可変周波数発振子（VXO）を実装。

### 6.1 VXO 回路概要

バリキャップダイオード（VR6, VR7）により周波数を可変制御。各 VXO 出力は DDS（Si5351）のクロック入力へ接続される。

周波数可変範囲: バリキャップ制御により調整可能

周波数可変範囲: バリキャップ制御により調整可能

### 6.4 DDS（Si5351）との接続

各 VXO 出力は Si5351_DIP8（U1）のクロック入力（CLK1GND, CLK1SDA）へ接続。

Si5351 により、VXO 出力をさらに安定化・分周して複数の周波数を生成。

## 6. DDS 出力フィルター

Si5351 DDS から出力される矩形波には高調波が含まれるため、LC フィルターにより高調波ノイズを除去し、きれいな信号を得る。

### 6.1 DDS 出力フィルター1（チャネル1）

Si5351 CLK0/CLK1 出力用フィルター

部品 | 仕様・役割
L16 | 100nH インダクタ（LC フィルター）
C129 | 47pF コンデンサ（LC フィルター）
VR6 | 500Ω 可変抵抗（出力レベル調整）
C115 | 0.01μ カップリングコンデンサ

### 6.2 DDS 出力フィルター2（チャネル2）

Si5351 CLK1SDA/CLK1GND 出力用フィルター

部品 | 仕様・役割
L17 | 100nH インダクタ（LC フィルター）
C130 | 47pF コンデンサ（LC フィルター）
VR7 | 500Ω 可変抵抗（出力レベル調整）
C116 | 0.01μ カップリングコンデンサ

### 6.3 フィルター機能

- L16/L17 + C129/C130: Si5351 矩形波出力の高調波ノイズを除去する LC フィルター
- VR6/VR7: 各チャネルの出力レベルを調整
- C115/C116: カップリングコンデンサで DC をカット
- 結果: 基本周波数成分のみの安定した信号を得られる

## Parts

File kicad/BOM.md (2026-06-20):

# PSN_TRX 部品表（BOM）

50MHz 帯 PSN 方式 SSB トランシーバ。  
スケマティック (`PSN_TRX.kicad_sch`) から生成・手動補完。

機械可読版は [`bom.csv`](bom.csv)。

> **最終更新: 2026-06-17**
> - Q8: 2SC1971 → **RD06HVF1**（RF N-ch MOSFET）に換装
> - Q3: 3SK59 (TO-72 THT) → **BF998 (SOT-143 SMD)**（デュアルゲート MOSFET）に換装
> - D3, D4: 削除（VR3 pin3 を GND へ直結配線）
> - R20: 10Ω → **0R**（ソース直結 GND）

---

## 抵抗 R（固定）

| Reference | 値 | フットプリント | 数量 |
|---|---|---|---|
| R1 | 120Ω | R_Axial_DIN0207 縦 | 1 |
| R3 | 4.7Ω | R_Axial_DIN0207 縦 | 1 |
| R4 | 1.5kΩ | R_Axial_DIN0207 縦 | 1 |
| R15, R34, R41, R44 | 100Ω | R_Axial_DIN0207 縦 | 4 |
| R17, R6, R8, R20, R23, R42 | 100kΩ | R_Axial_DIN0207 縦 | 6 |
| R21 | 220kΩ | R_Axial_DIN0207 縦 | 1 |
| R5, R7, R9, R10, R13, R18, R22, R24, R33, R40 | 1kΩ | R_Axial_DIN0207 縦 | 10 |
| R25, R30, R43 | 330Ω | R_Axial_DIN0207 縦 | 3 |
| R11, R12, R16, R26, R27 | 10kΩ | R_Axial_DIN0207 縦 | 5 |
| R2, R28, R31 | 1MΩ | R_Axial_DIN0207 縦 | 3 |
| R14, R35 | 20kΩ | R_Axial_DIN0207 縦 | 2 |
| R36, R39, R51 | 51Ω | R_Axial_DIN0207 縦 | 3 |
| R29, R32, R38 | 4.7kΩ | R_Axial_DIN0207 縦 | 3 |

**固定抵抗 合計: 43本**

---

## 抵抗 R（1W PA バイアス回路）

| Reference | 値 | フットプリント | 備考 |
|---|---|---|---|
| R22（PA） | 470Ω | R_Axial_DIN0207 横 P10.16mm | ゲートバイアス上側分圧 |
| R21（PA） | 10Ω | R_Axial_DIN0207 横 P10.16mm | ゲートストッパー |
| R20（PA） | **0R（ジャンパ）** | R_Axial_DIN0207 横 P10.16mm | ソース直結 GND（ジャンパ線で代替可） |

---

## 可変抵抗 VR

| Reference | 値 | フットプリント | 数量 | 備考 |
|---|---|---|---|---|
| VR1 | 5kΩ | PinHeader_1x03 P2.54mm（外付け） | 1 | |
| VR2 | 10kΩ | PinHeader_1x03 P2.54mm（外付け） | 1 | |
| VR3 | 500Ω | Potentiometer_Bourns_3266W_Vertical | 1 | Idq 調整用トリマポット（50〜80mA に設定） |
| VR4, VR5 | 1kΩ | Potentiometer_Alps_RK09K_Single_Vertical | 2 | |

---

## コンデンサ C（無極性：セラミック／フィルム）

| Reference | 値 | フットプリント | 数量 |
|---|---|---|---|
| C21, C22, C3 | 0.001μF (1000pF) | C_Disc D5.0mm | 3 |
| C100, C101, C103, C111, C112, C113, C114, C115, C116, C117, C118, C119, C120, C121, C124, C125, C126 | 0.01μF | C_Disc D5.0mm | 17 |
| C4, C6, C7 | 0.1μF | C_Disc D5.0mm | 3 |
| C102, C104, C105, C122, C123 | 1μF | C_Disc D5.0mm | 5 |
| C9, C10 | 100pF | C_Disc D3.0mm | 2 |
| C11, C12, C14 | 47pF | C_Disc D3.0mm | 3 |
| C19, C20 | 33pF | C_Disc D3.0mm | 2 |
| C1, C2, C17, C18, C23, C24, C31 | 15pF | C_Disc D3.0mm | 7 |
| C13, C32 | 5pF | C_Disc D3.0mm | 2 |

**無極性コンデンサ 合計: 44個**

---

## コンデンサ C（電解：有極性）

| Reference | 値 | フットプリント | 数量 |
|---|---|---|---|
| C5, C8, C8b1 | 10μF | CP_Radial D5.0mm P2.00mm | 3 |
| C28, C30 | 100μF | CP_Radial D6.3mm P2.50mm | 2 |
| C158, C159, C160, C161, C162, C163, C164, C165, C166, C167, C168 | 1μF | CP_Radial D5.0mm P2.00mm | 11 |

**電解コンデンサ 合計: 16個**

---

## トリマコンデンサ TC

| Reference | 値 | フットプリント | 数量 |
|---|---|---|---|
| TC1, TC2 | 40pF | PSN_TRX:C_Trimmer_TMCV01 | 2 |

---

## コイル L・インダクタ

| Reference | 値 | フットプリント | 数量 | 説明 |
|---|---|---|---|---|
| L1, L2, L6, L7, L11, L12, L13 | 7T50 | PSN_TRX:L_FCZ07S_CT | 7 | FCZ07S コイル（センタータップ付） |
| L3 | 7T5 | PSN_TRX:L_FCZ07S_CT | 1 | FCZ07S コイル |
| L4 | T-30-10 6T/0.4mm | PSN_TRX:L_T30_2pin_Vertical | 1 | T-30 トロイダルコア 6巻 |
| L5 | T-30-10 6T+1T/0.4mm | PSN_TRX:L_T30_3pin_Vertical | 1 | T-30 トロイダルコア タップ付 |
| L9, L10 | 1mH | PSN_TRX:L_AL0510-153K_Vertical | 2 | AL0510-153K 縦型インダクタ |
| L8 | 15mH | PSN_TRX:L_AL0510-153K_Vertical | 1 | AL0510-153K 縦型インダクタ |
| L14, L15 | T-50-10 18T/0.4mm | PSN_TRX:L_T50_2pin_Vertical | 2 | T-50 トロイダルコア 18巻 |
| RFC1 | 10μH | PSN_TRX:L_AL0510-153K_Vertical | 1 | ドレイン側 RFチョーク（1W PA） |

---

## ダイオード D

| Reference | 値 | フットプリント | 数量 | 備考 |
|---|---|---|---|---|
| D1, D2, D3, D4, D7, D8 | 1N60 | D_DO-35 縦型 CathodeUp | 6 | ゲルマニウム検波ダイオード |

---

## トランジスタ Q

| Reference | 型番 | パッケージ | 数量 | 種別・備考 |
|---|---|---|---|---|
| **Q3** | **BF998** | **SOT-143 (SMD)** | **1** | **RF デュアルゲート N-ch MOSFET（2026-06-17 変更）** |
| Q4, Q11, Q12, Q13, Q15, Q17 | 2SC1815 | TO-92 | 6 | NPN 汎用トランジスタ |
| Q9, Q10, Q14 | 2SK439 | TO-92 | 3 | N-ch JFET |
| Q5 | 2SC2120 | TO-92 | 1 | NPN 中電力トランジスタ |
| Q6 | 2SA950 | TO-92 | 1 | PNP 中電力トランジスタ |
| Q2, Q7 | 2SC1923 | TO-92 | 2 | NPN 高周波トランジスタ |
| **Q8** | **RD06HVF1** | **TO-220F** | **1** | **1W PA 終段 RF N-ch MOSFET（175MHz, 6W）（2026-06-17 変更）** |

---

## IC・モジュール

| Reference | 型番 | パッケージ | 数量 | 説明 |
|---|---|---|---|---|
| IC1 | LP2950L-5.0V | TO-92 | 1 | 5V 三端子レギュレータ |
| IC2 | NJM2904 | DIP-8 | 3 | デュアル OP アンプ |
| U2 | AE-Si5351A | DIP-8 変換基板 | 1 | I2C クロックジェネレーターモジュール |
| A1 | XIAO ESP32C3 | ソケット実装 | 1 | Seeed Studio XIAO ESP32C3（VFO 制御） |

---

## トランス T

| Reference | 型番 | フットプリント | 数量 | 説明 |
|---|---|---|---|---|
| T1 | ST-71 | PSN_TRX:Transformer_ST71_CB19 | 1 | 山水 ST-71（音声トランス、CB-19 リード型） |

---

## リレー K

| Reference | 型番 | フットプリント | 数量 | 説明 |
|---|---|---|---|---|
| K1 | G5V-2 | Relay_DPDT_Omron_G5V-2 | 1 | オムロン DPDT リレー（TX/RX 切替） |

---

## 水晶振動子 X

| Reference | 値 | フットプリント | 数量 | 説明 |
|---|---|---|---|---|
| X1 | 50.5MHz/3 | Crystal_HC49-4H_Vertical | 1 | HC49 縦型水晶（VXO 用、約 16.833MHz） |

---

## LED

| Reference | 値 | フットプリント | 数量 |
|---|---|---|---|
| LED1 | LED（赤） | PinHeader_1x02 P2.54mm（外付け） | 1 |
| LED2 | LED（黄） | PinHeader_1x02 P2.54mm（外付け） | 1 |

---

## スイッチ SW

| Reference | 型番 | フットプリント | 数量 |
|---|---|---|---|
| SW1, SW2 | DIP スライドスイッチ | SW_DIP_SPSTx01_Slide_6.7x4.1mm | 2 |

---

## コネクタ J

| Reference | 機能 | フットプリント | 数量 |
|---|---|---|---|
| J1, J2, J3 | PWR_IN（電源入力） | PinHeader_1x02 P2.54mm | 3 |
| J4 | MIC-IN（マイク入力） | PinHeader_1x02 P2.54mm | 1 |
| J5 | FREQ-VC | PinHeader_1x02 P2.54mm | 1 |
| J6 | Volume（音量） | PinHeader_1x03 P2.54mm | 1 |

---

## 部品点数サマリ

| カテゴリ | 種類数 | 合計数量 |
|---|---|---|
| 固定抵抗 | 13 種 | 43 本 |
| 1W PA バイアス抵抗 | 3 種 | 3 本 |
| 可変抵抗・トリマポット | 4 種 | 5 個 |
| 無極性コンデンサ | 9 種 | 44 個 |
| 電解コンデンサ | 3 種 | 16 個 |
| トリマコンデンサ | 1 種 | 2 個 |
| FCZ07S コイル | 2 値 | 8 個 |
| トロイダルコイル（T-30/T-50） | 3 種 | 4 個 |
| 固定インダクタ（AL0510） | 2 値 | 3 個 |
| RFチョーク | 1 種 | 1 個 |
| ゲルマニウムダイオード | 1 種 | 6 個 |
| トランジスタ（BJT/JFET/MOSFET） | 7 種 | 15 個 |
| IC | 2 種 | 4 個 |
| モジュール（AE-Si5351A） | 1 種 | 1 個 |
| マイコンモジュール（XIAO ESP32C3） | 1 種 | 1 個 |
| 音声トランス | 1 種 | 1 個 |
| リレー | 1 種 | 1 個 |
| 水晶振動子 | 1 種 | 1 個 |
| LED | 2 種 | 2 個 |
| スイッチ | 1 種 | 2 個 |
| コネクタ（ピンヘッダ） | 4 種 | 6 個 |

---

## 注意事項

- **kicad/ フォルダが最新版**。`transceiver/` フォルダは旧設計のため参照不要。
- **Q3 (BF998)** は SMD（SOT-143）部品。手実装の場合ピン配置に注意。
- **Q8 (RD06HVF1)** は 12V 動作の RF MOSFET。TO-220F パッケージ（絶縁型）。ドレインへの放熱対策を施すこと。
- **R20 (0R)** はジャンパ線での代替可能。
- **VR3** は Bourns 3266W 500Ω トリマポット。Idq を 50〜80mA に調整する。
- **AE-Si5351A** は Aitendo 等で入手可能な I2C クロックジェネレーターモジュール（DIP-8 変換基板付き）。

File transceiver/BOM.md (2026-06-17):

# PSN_TRX 部品表（BOM）

50MHz 帯 PSN 方式 SSB トランシーバ。
スケマティック (`PSN_TRX.kicad_sch`) から自動生成。

機械可読版は [`bom.csv`](bom.csv)。

---

## 抵抗 R

| Reference | Value | Footprint | Qty |
|---|---|---|---|
| R1 | 120 | Resistor_THT:R_Axial_DIN0207_L6.3mm_D2.5mm_P2.54mm_Vertical | 1 |
| R15, R44, R41, R34 | 100 | Resistor_THT:R_Axial_DIN0207_L6.3mm_D2.5mm_P2.54mm_Vertical | 4 |
| R2 | 1M | Resistor_THT:R_Axial_DIN0207_L6.3mm_D2.5mm_P2.54mm_Vertical | 1 |
| R21 | 220k | Resistor_THT:R_Axial_DIN0207_L6.3mm_D2.5mm_P2.54mm_Vertical | 1 |
| R25, R29, R43 | 330 | Resistor_THT:R_Axial_DIN0207_L6.3mm_D2.5mm_P2.54mm_Vertical | 3 |
| R26, R12, R16, R27, R11 | 10k | Resistor_THT:R_Axial_DIN0207_L6.3mm_D2.5mm_P2.54mm_Vertical | 5 |
| R3 | 4.7 | Resistor_THT:R_Axial_DIN0207_L6.3mm_D2.5mm_P2.54mm_Vertical | 1 |
| R31, R17, R6, R28, R42, R23, R8, R20 | 100k | Resistor_THT:R_Axial_DIN0207_L6.3mm_D2.5mm_P2.54mm_Vertical | 8 |
| R32, R24, R13, R30, R33, R18, R7, R5, R40, R9, R10, R22 | 1k | Resistor_THT:R_Axial_DIN0207_L6.3mm_D2.5mm_P2.54mm_Vertical | 12 |
| R35, R14 | 20k | Resistor_THT:R_Axial_DIN0207_L6.3mm_D2.5mm_P2.54mm_Vertical | 2 |
| R38 | 4.7k | Resistor_THT:R_Axial_DIN0207_L6.3mm_D2.5mm_P2.54mm_Vertical | 1 |
| R4 | 1.5k | Resistor_THT:R_Axial_DIN0207_L6.3mm_D2.5mm_P2.54mm_Vertical | 1 |
| R52, R36, R51 | 51 | Resistor_THT:R_Axial_DIN0207_L6.3mm_D2.5mm_P2.54mm_Vertical | 3 |

## コンデンサ C

| Reference | Value | Footprint | Qty |
|---|---|---|---|
| C11, C14, C12 | 47p | Capacitor_THT:C_Disc_D3.0mm_W1.6mm_P2.50mm | 3 |
| C119, C113, C124, C115, C118, C104, C112, C117, C105, C100, C126, C122, C102, C114, C120, C121, C103, C116, C111, C125, C123, C101 | 0.01u | Capacitor_THT:C_Disc_D5.0mm_W2.5mm_P2.50mm | 22 |
| C163, C165, C162, C159, C164, C158, C160, C166, C167, C161 | 1u | Capacitor_THT:CP_Radial_D5.0mm_P2.00mm | 10 |
| C20, C29, C3 | 0.001u | Capacitor_THT:C_Disc_D5.0mm_W2.5mm_P2.50mm | 3 |
| C25, C19 | 33p | Capacitor_THT:C_Disc_D3.0mm_W1.6mm_P2.50mm | 2 |
| C28, C30 | 100u | Capacitor_THT:CP_Radial_D6.3mm_P2.50mm | 2 |
| C31, C23, C18, C17, C1, C24, C2 | 15p | Capacitor_THT:C_Disc_D3.0mm_W1.6mm_P2.50mm | 7 |
| C32, C13 | 5p | Capacitor_THT:C_Disc_D3.0mm_W1.6mm_P2.50mm | 2 |
| C4, C6, C7 | 0.1u | Capacitor_THT:C_Disc_D5.0mm_W2.5mm_P2.50mm | 3 |
| C5, C8, C8b1 | 10u | Capacitor_THT:CP_Radial_D5.0mm_P2.00mm | 3 |
| C9, C10 | 100p | Capacitor_THT:C_Disc_D3.0mm_W1.6mm_P2.50mm | 2 |

## コイル L

| Reference | Value | Footprint | Qty |
|---|---|---|---|
| L1, L7, L6, L12, L11, L2, L3, L13 | 7T50 | PSN_TRX:L_FCZ07S_CT | 8 |
| L10, L9 | 1mH | PSN_TRX:L_AL0510-153K_Vertical | 2 |
| L14, L15 | T-50-10 18T/0.4mm | PSN_TRX:L_T50_2pin_Vertical | 2 |
| L4 | T-30-10 6T/0.4mm | PSN_TRX:L_T30_2pin_Vertical | 1 |
| L5 | T-30-10 6T+1T/0.4mm | PSN_TRX:L_T30_3pin_Vertical | 1 |
| L8 | 15mH | PSN_TRX:L_AL0510-153K_Vertical | 1 |
| LED1 | LED | Connector_PinHeader_2.54mm:PinHeader_1x02_P2.54mm_Vertical | 1 |
| LED2 | LED黄 | Connector_PinHeader_2.54mm:PinHeader_1x02_P2.54mm_Vertical | 1 |

## ダイオード D

| Reference | Value | Footprint | Qty |
|---|---|---|---|
| D8, D1, D7, D3, D2, D4 | 1N60 | Diode_THT:D_DO-35_SOD27_P2.54mm_Vertical_CathodeUp | 6 |

## トランス T

| Reference | Value | Footprint | Qty |
|---|---|---|---|
| T1 | ST-71 | PSN_TRX:Transformer_ST71_CB19 | 1 |
| TC2, TC1 | 40p | PSN_TRX:C_Trimmer_TMCV01 | 2 |
| TC3 | 30p | PSN_TRX:C_Trimmer_TMCV01 | 1 |

## トランジスタ Q

| Reference | Value | Footprint | Qty |
|---|---|---|---|
| **Q3** | **BF998** | PSN_TRX:BF998_SOT143 | 1 |
| Q12, Q17, Q11, Q13, Q4, Q15 | 2SC1815 | Package_TO_SOT_THT:TO-92_Inline | 6 |
| Q14, Q10, Q9 | 2SK439 | Package_TO_SOT_THT:TO-92_Inline | 3 |
| Q5 | 2SC2120 | Package_TO_SOT_THT:TO-92_Inline | 1 |
| Q6 | 2SA950 | Package_TO_SOT_THT:TO-92_Inline | 1 |
| **Q8** | **RD06HVF1** | Package_TO_SOT_THT:TO-220-3_Vertical | 1 |
| Q2, Q7 | 2SC1923 | Package_TO_SOT_THT:TO-92_Inline | 2 |

## 水晶振動子

| Reference | Value | Footprint | Qty |
|---|---|---|---|
| X1 | 50.5MHz/3 | Crystal:Crystal_HC49-4H_Vertical | 1 |

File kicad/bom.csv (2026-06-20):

Reference | 品名/型番 | 値/仕様 | フットプリント | 数量 | 入手先
C1, C2, C5, C8, C10 | セラミックコンデンサ | 1u | Capacitor_THT:C_Disc_D5.0mm_W2.5mm_P2.50mm | 5 | 秋月電子
C3, C4, C9 | セラミックコンデンサ | 0.1u | Capacitor_THT:C_Disc_D5.0mm_W2.5mm_P2.50mm | 3 | 秋月電子
C6, C12, C22, C30, C34, C37 | セラミックコンデンサ | 15p | Capacitor_THT:C_Disc_D3.0mm_W1.6mm_P2.50mm | 6 | 秋月電子
C7, C13, C14, C15, C23, C24, C25, C32, C33, C35, C36, C39, C40, C45, C48, C49 | セラミックコンデンサ | 0.01u | Capacitor_THT:C_Disc_D5.0mm_W2.5mm_P2.50mm | 16 | 秋月電子
C11, C16 | 電解コンデンサ | 100u | Capacitor_THT:CP_Radial_D6.3mm_P2.50mm | 2 | 秋月電子
C17, C18, C19, C20 | 電解コンデンサ | 10u | Capacitor_THT:CP_Radial_D5.0mm_P2.00mm | 4 | 秋月電子
C21, C38, C44 | セラミックコンデンサ | 0.001u | Capacitor_THT:C_Disc_D5.0mm_W2.5mm_P2.50mm | 3 | 秋月電子
C27 | セラミックコンデンサ | 0.1uF | Capacitor_THT:C_Disc_D5.0mm_W2.5mm_P5.00mm | 1 | 秋月電子
C28, C29 | セラミックコンデンサ | 100pF | Capacitor_THT:C_Disc_D5.0mm_W2.5mm_P5.00mm | 2 | 秋月電子
C31 | セラミックコンデンサ | 22pF | Capacitor_THT:C_Disc_D5.0mm_W2.5mm_P5.00mm | 1 | 秋月電子
C41, C42, C46, C47 | セラミックコンデンサ | 47PF | Capacitor_THT:C_Disc_D5.0mm_W2.5mm_P2.50mm | 4 | 秋月電子
C43 | セラミックコンデンサ | 5p | Capacitor_THT:C_Disc_D3.0mm_W1.6mm_P2.50mm | 1 | 秋月電子
C50, C51, C52, C53, C54, C55, C56, C57, C58, C59, C60 | 電解コンデンサ | 1u | Capacitor_THT:CP_Radial_D5.0mm_P2.00mm | 11 | 秋月電子
D1, D2, D5, D6, D7, D8 | ゲルマニウムダイオード 1N60 | 1N60 | Diode_THT:D_DO-35_SOD27_P2.54mm_Vertical_CathodeUp | 6 | 秋月電子／サトー電気
IC1 | 三端子レギュレータ LP2950L | LP2950L-5.0V | Package_TO_SOT_THT:TO-92_Inline | 1 | 秋月電子
IC2 | デュアル OP アンプ NJM2904 | NJM2904 | Package_DIP:DIP-8_W7.62mm | 1 | 秋月電子
J1 | ピンヘッダ | RF_IN | Connector_PinHeader_2.54mm:PinHeader_1x02_P2.54mm_Vertical | 1 | 秋月電子
J2 | ピンヘッダ | SP-OUT | Connector_PinHeader_2.54mm:PinHeader_1x02_P2.54mm_Vertical | 1 | 秋月電子
J3 | ピンヘッダ | PWR_IN | Connector_PinHeader_2.54mm:PinHeader_1x02_P2.54mm_Vertical | 1 | 秋月電子
J4, J5 | ピンヘッダ | Volume | Connector_PinHeader_2.54mm:PinHeader_1x03_P2.54mm_Vertical | 2 | 秋月電子
J6 | ピンヘッダ | Encoder | Connector_PinHeader_2.54mm:PinHeader_1x04_P2.54mm_Vertical | 1 | 秋月電子
J7 | ピンヘッダ | I2C_OUT-LCD | Connector_PinHeader_2.54mm:PinHeader_1x03_P2.54mm_Vertical | 1 | 秋月電子
J8 | ピンヘッダ | MIC-IN | Connector_PinHeader_2.54mm:PinHeader_1x04_P2.54mm_Vertical | 1 | 秋月電子
J9 | ピンヘッダ | TX-ON-LED | Connector_PinHeader_2.54mm:PinHeader_1x02_P2.54mm_Vertical | 1 | 秋月電子
J10 | ピンヘッダ | TJC4832T135 | Connector_PinHeader_2.54mm:PinHeader_1x04_P2.54mm_Vertical | 1 | 秋月電子
K1 | リレー（DPDT） | G5V-2 | Relay_THT:Relay_DPDT_Omron_G5V-2 | 1 | 秋月電子
L1, L2, L3, L7, L8, L9 | FCZ07S コイル（センタータップ付） | 7T50 | PSN_TRX:L_FCZ07S_CT | 6 | サトー電気
L4, L5 | T-50-10 トロイダルコイル 18巻 | T-50-10 18T/0.4mm | PSN_TRX:L_T50_2pin_Vertical | 2 | サトー電気
L6 | 固定インダクタ（アキシャル） | 47nH | Inductor_THT:L_Axial_L9.5mm_D4.0mm_P12.70mm_Horizontal_Fastron_SMCC | 1 | 秋月電子
L10, L11 | 固定インダクタ AL0510 | 100nH | PSN_TRX:L_AL0510-153K_Vertical | 2 | サトー電気
L12, L13 | 固定インダクタ AL0510 | 1mH | PSN_TRX:L_AL0510-153K_Vertical | 2 | サトー電気
L14 | 固定インダクタ AL0510 | 15mH | PSN_TRX:L_AL0510-153K_Vertical | 1 | サトー電気
LED1 | LED | LED | Connector_PinHeader_2.54mm:PinHeader_1x02_P2.54mm_Vertical | 1 | 秋月電子
LED2 | LED | LED黄 | Connector_PinHeader_2.54mm:PinHeader_1x02_P2.54mm_Vertical | 1 | 秋月電子
Q1 | NPN トランジスタ 2SC2120 | 2SC2120 | Package_TO_SOT_THT:TO-92_Inline | 1 | 秋月電子／サトー電気
Q2, Q5, Q9, Q11, Q12, Q13, Q14 | NPN トランジスタ 2SC1815 | 2SC1815 | Package_TO_SOT_THT:TO-92_Inline | 7 | 秋月電子／サトー電気
Q3 | デュアルゲート MOSFET（SMD） BF998 | BF998 | PSN_TRX:BF998_SOT143 | 1 | Mouser／Digikey
Q4 | NPN トランジスタ 2SC1923 | 2SC1923 | Package_TO_SOT_THT:TO-92_Inline | 1 | サトー電気
Q6 | PNP トランジスタ 2SA950 | 2SA950 | Package_TO_SOT_THT:TO-92_Inline | 1 | 秋月電子／サトー電気
Q7, Q10 | N-ch JFET 2SK439 | 2SK439 | Package_TO_SOT_THT:TO-92_Inline | 2 | 秋月電子／サトー電気
Q8 | RF N-ch MOSFET RD06HVF1（1W PA 終段） | RD06HVF1 | Package_TO_SOT_THT:TO-220-3_Vertical | 1 | 秋月電子
R1, R2, R17, R35 | 固定抵抗 1/4W | 100k | Resistor_THT:R_Axial_DIN0207_L6.3mm_D2.5mm_P2.54mm_Vertical | 4 | 秋月電子
R3 | 固定抵抗 1/4W | 1.5k | Resistor_THT:R_Axial_DIN0207_L6.3mm_D2.5mm_P2.54mm_Vertical | 1 | 秋月電子
R4, R7, R11, R12, R16, R25, R32, R36, R41 | 固定抵抗 1/4W | 1k | Resistor_THT:R_Axial_DIN0207_L6.3mm_D2.5mm_P2.54mm_Vertical | 9 | 秋月電子
R5, R37, R39 | 固定抵抗 1/4W | 330 | Resistor_THT:R_Axial_DIN0207_L6.3mm_D2.5mm_P2.54mm_Vertical | 3 | 秋月電子
R6, R8, R31, R34 | 固定抵抗 1/4W | 10k | Resistor_THT:R_Axial_DIN0207_L6.3mm_D2.5mm_P2.54mm_Vertical | 4 | 秋月電子
R9, R33, R40 | 固定抵抗 1/4W | 1M | Resistor_THT:R_Axial_DIN0207_L6.3mm_D2.5mm_P2.54mm_Vertical | 3 | 秋月電子
R10 | 固定抵抗 1/4W | 4.7 | Resistor_THT:R_Axial_DIN0207_L6.3mm_D2.5mm_P2.54mm_Vertical | 1 | 秋月電子
R13 | 固定抵抗 1/4W | 120 | Resistor_THT:R_Axial_DIN0207_L6.3mm_D2.5mm_P2.54mm_Vertical | 1 | 秋月電子
R14, R28 | 固定抵抗 1/4W | 100 | Resistor_THT:R_Axial_DIN0207_L6.3mm_D2.5mm_P2.54mm_Vertical | 2 | 秋月電子
R15, R19 | 固定抵抗 1/4W | 20k | Resistor_THT:R_Axial_DIN0207_L6.3mm_D2.5mm_P2.54mm_Vertical | 2 | 秋月電子
R18, R23, R26 | 固定抵抗 1/4W | 51 | Resistor_THT:R_Axial_DIN0207_L6.3mm_D2.5mm_P2.54mm_Vertical | 3 | 秋月電子
R21 | 固定抵抗 1/4W | 10 | Resistor_THT:R_Axial_DIN0207_L6.3mm_D2.5mm_P5.08mm_Vertical | 1 | 秋月電子
R22 | 固定抵抗 1/4W | 470 | Resistor_THT:R_Axial_DIN0207_L6.3mm_D2.5mm_P5.08mm_Vertical | 1 | 秋月電子
R24, R30, R38 | 固定抵抗 1/4W | 4.7k | Resistor_THT:R_Axial_DIN0207_L6.3mm_D2.5mm_P2.54mm_Vertical | 3 | 秋月電子
R27, R29 | 固定抵抗 1/4W | 47 | Resistor_THT:R_Axial_DIN0207_L6.3mm_D2.5mm_P2.54mm_Vertical | 2 | 秋月電子
RFC1 | RFチョーク | 10uH | Inductor_THT:L_Axial_L9.5mm_D4.0mm_P12.70mm_Horizontal_Fastron_SMCC | 1 | 秋月電子
SW1, SW2 | DIP スライドスイッチ | SW | Button_Switch_THT:SW_DIP_SPSTx01_Slide_6.7x4.1mm_W7.62mm_P2.54mm_LowProfile | 2 | 秋月電子
Studio XIAO ESP32C3 | Seeeduino_XIAO_Socket | Seeeduino_XIAO_Socket | PSN_TRX:Seeeduino_XIAO_Socket | 1 | 秋月電子
T1 | 音声トランス 山水 ST-71 | ST-71 | PSN_TRX:Transformer_ST71_CB19 | 1 | サトー電気
TC1 | トリマコンデンサ TMCV01（50pF 代替可） | 30p | PSN_TRX:C_Trimmer_TMCV01 | 1 | 秋月電子
U1 | 三端子レギュレータ LP2950L | LP2950-3.3_TO92 | Package_TO_SOT_THT:TO-92_Inline | 1 | 秋月電子
U2 | クロックジェネレーターモジュール Si5351A | Si5351_DIP8 | PSN_TRX:DIP-8_W7.62mm | 1 | 秋月電子
VR3 | トリマポット Bourns 3266W | 500 | Potentiometer_THT:Potentiometer_Bourns_3266W_Vertical | 1 | 秋月電子
VR4, VR6 | ボリューム TOCOS GF063P | 1k | PSN_TRX:Potentiometer_TOCOS_GF063P_Vertical | 2 | 秋月電子
VR5, VR7 | ボリューム TOCOS GF063P | 500 | PSN_TRX:Potentiometer_TOCOS_GF063P_Vertical | 2 | 秋月電子
VR8 | ボリューム TOCOS GF063P | 10k | PSN_TRX:Potentiometer_TOCOS_GF063P_Vertical | 1 | 秋月電子

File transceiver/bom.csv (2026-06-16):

Reference | Value | Footprint | Qty
C20, C29, C3 | 0.001u | Capacitor_THT:C_Disc_D5.0mm_W2.5mm_P2.50mm | 3
C119, C113, C124, C115, C118, C104, C112, C117, C105, C100, C126, C122, C102, C114, C120, C121, C103, C116, C111, C125, C123, C101 | 0.01u | Capacitor_THT:C_Disc_D5.0mm_W2.5mm_P2.50mm | 22
C4, C6, C7 | 0.1u | Capacitor_THT:C_Disc_D5.0mm_W2.5mm_P2.50mm | 3
VC | 0p | PSN_TRX:C_Trimmer_TMCV01 | 1
R4 | 1.5k | Resistor_THT:R_Axial_DIN0207_L6.3mm_D2.5mm_P2.54mm_Vertical | 1
R15, R44, R41, R34 | 100 | Resistor_THT:R_Axial_DIN0207_L6.3mm_D2.5mm_P2.54mm_Vertical | 4
R31, R17, R6, R28, R42, R23, R8, R20 | 100k | Resistor_THT:R_Axial_DIN0207_L6.3mm_D2.5mm_P2.54mm_Vertical | 8
C9, C10 | 100p | Capacitor_THT:C_Disc_D3.0mm_W1.6mm_P2.50mm | 2
C28, C30 | 100u | Capacitor_THT:CP_Radial_D6.3mm_P2.50mm | 2
VR2 | 10k | Connector_PinHeader_2.54mm:PinHeader_1x03_P2.54mm_Vertical | 1
VR3 | 10k | Potentiometer_THT:Potentiometer_Alps_RK09K_Single_Vertical | 1
R26, R12, R16, R27, R11 | 10k | Resistor_THT:R_Axial_DIN0207_L6.3mm_D2.5mm_P2.54mm_Vertical | 5
C5, C8, C8b1 | 10u | Capacitor_THT:CP_Radial_D5.0mm_P2.00mm | 3
R1 | 120 | Resistor_THT:R_Axial_DIN0207_L6.3mm_D2.5mm_P2.54mm_Vertical | 1
L8 | 15mH | PSN_TRX:L_AL0510-153K_Vertical | 1
C31, C23, C18, C17, C1, C24, C2 | 15p | Capacitor_THT:C_Disc_D3.0mm_W1.6mm_P2.50mm | 7
R2 | 1M | Resistor_THT:R_Axial_DIN0207_L6.3mm_D2.5mm_P2.54mm_Vertical | 1
D8, D1, D7, D3, D2, D4 | 1N60 | Diode_THT:D_DO-35_SOD27_P2.54mm_Vertical_CathodeUp | 6
VR5, VR4 | 1k | Potentiometer_THT:Potentiometer_Alps_RK09K_Single_Vertical | 2
R32, R24, R13, R30, R33, R18, R7, R5, R40, R9, R10, R22 | 1k | Resistor_THT:R_Axial_DIN0207_L6.3mm_D2.5mm_P2.54mm_Vertical | 12
L10, L9 | 1mH | PSN_TRX:L_AL0510-153K_Vertical | 2
C163, C165, C162, C159, C164, C158, C160, C166, C167, C161 | 1u | Capacitor_THT:CP_Radial_D5.0mm_P2.00mm | 10
R35, R14 | 20k | Resistor_THT:R_Axial_DIN0207_L6.3mm_D2.5mm_P2.54mm_Vertical | 2
R21 | 220k | Resistor_THT:R_Axial_DIN0207_L6.3mm_D2.5mm_P2.54mm_Vertical | 1
Q6 | 2SA950 | Package_TO_SOT_THT:TO-92_Inline | 1
Q12, Q17, Q11, Q13, Q4, Q15, Q3 | 2SC1815 | Package_TO_SOT_THT:TO-92_Inline | 7
Q8, Q2, Q7 | 2SC1923 | Package_TO_SOT_THT:TO-92_Inline | 3
Q5 | 2SC2120 | Package_TO_SOT_THT:TO-92_Inline | 1
Q14, Q10, Q9 | 2SK439 | Package_TO_SOT_THT:TO-92_Inline | 3
TC3 | 30p | PSN_TRX:C_Trimmer_TMCV01 | 1
R25, R29, R43 | 330 | Resistor_THT:R_Axial_DIN0207_L6.3mm_D2.5mm_P2.54mm_Vertical | 3
C25, C19 | 33p | Capacitor_THT:C_Disc_D3.0mm_W1.6mm_P2.50mm | 2
Q1 | 3SK59 | Package_TO_SOT_THT:TO-72-4 | 1
R3 | 4.7 | Resistor_THT:R_Axial_DIN0207_L6.3mm_D2.5mm_P2.54mm_Vertical | 1
R38 | 4.7k | Resistor_THT:R_Axial_DIN0207_L6.3mm_D2.5mm_P2.54mm_Vertical | 1
TC2, TC1 | 40p | PSN_TRX:C_Trimmer_TMCV01 | 2
C11, C14, C12 | 47p | Capacitor_THT:C_Disc_D3.0mm_W1.6mm_P2.50mm | 3
X1 | 50.5MHz/3 | Crystal:Crystal_HC49-4H_Vertical | 1
R52, R36, R51 | 51 | Resistor_THT:R_Axial_DIN0207_L6.3mm_D2.5mm_P2.54mm_Vertical | 3
VR1 | 5k | Connector_PinHeader_2.54mm:PinHeader_1x03_P2.54mm_Vertical | 1
C32, C13 | 5p | Capacitor_THT:C_Disc_D3.0mm_W1.6mm_P2.50mm | 2
L1, L7, L6, L12, L11, L2, L3, L13 | 7T50 | PSN_TRX:L_FCZ07S_CT | 8
K1 | G5V-2 | Relay_THT:Relay_DPDT_Omron_G5V-2 | 1
LED1 | LED | Connector_PinHeader_2.54mm:PinHeader_1x02_P2.54mm_Vertical | 1
LED2 | LED黄 | Connector_PinHeader_2.54mm:PinHeader_1x02_P2.54mm_Vertical | 1
IC1 | LP2950L-5.0V | Package_TO_SOT_THT:TO-92_Inline | 1
MIC1 | MIC | Connector_PinHeader_2.54mm:PinHeader_1x02_P2.54mm_Vertical | 1
IC2, IC2, IC2 | NJM2904 | Package_DIP:DIP-8_W7.62mm | 3
J1 | PWR_IN | Connector_PinHeader_2.54mm:PinHeader_1x02_P2.54mm_Vertical | 1
T1 | ST-71 | PSN_TRX:Transformer_ST71_CB19 | 1
SW1 | SW | Button_Switch_THT:SW_DIP_SPSTx01_Slide_6.7x4.1mm_W7.62mm_P2.54mm_LowProfile | 1
L5 | T-30-10 6T+1T/0.4mm | PSN_TRX:L_T30_3pin_Vertical | 1
L4 | T-30-10 6T/0.4mm | PSN_TRX:L_T30_2pin_Vertical | 1
L14, L15 | T-50-10 18T/0.4mm | PSN_TRX:L_T50_2pin_Vertical | 2

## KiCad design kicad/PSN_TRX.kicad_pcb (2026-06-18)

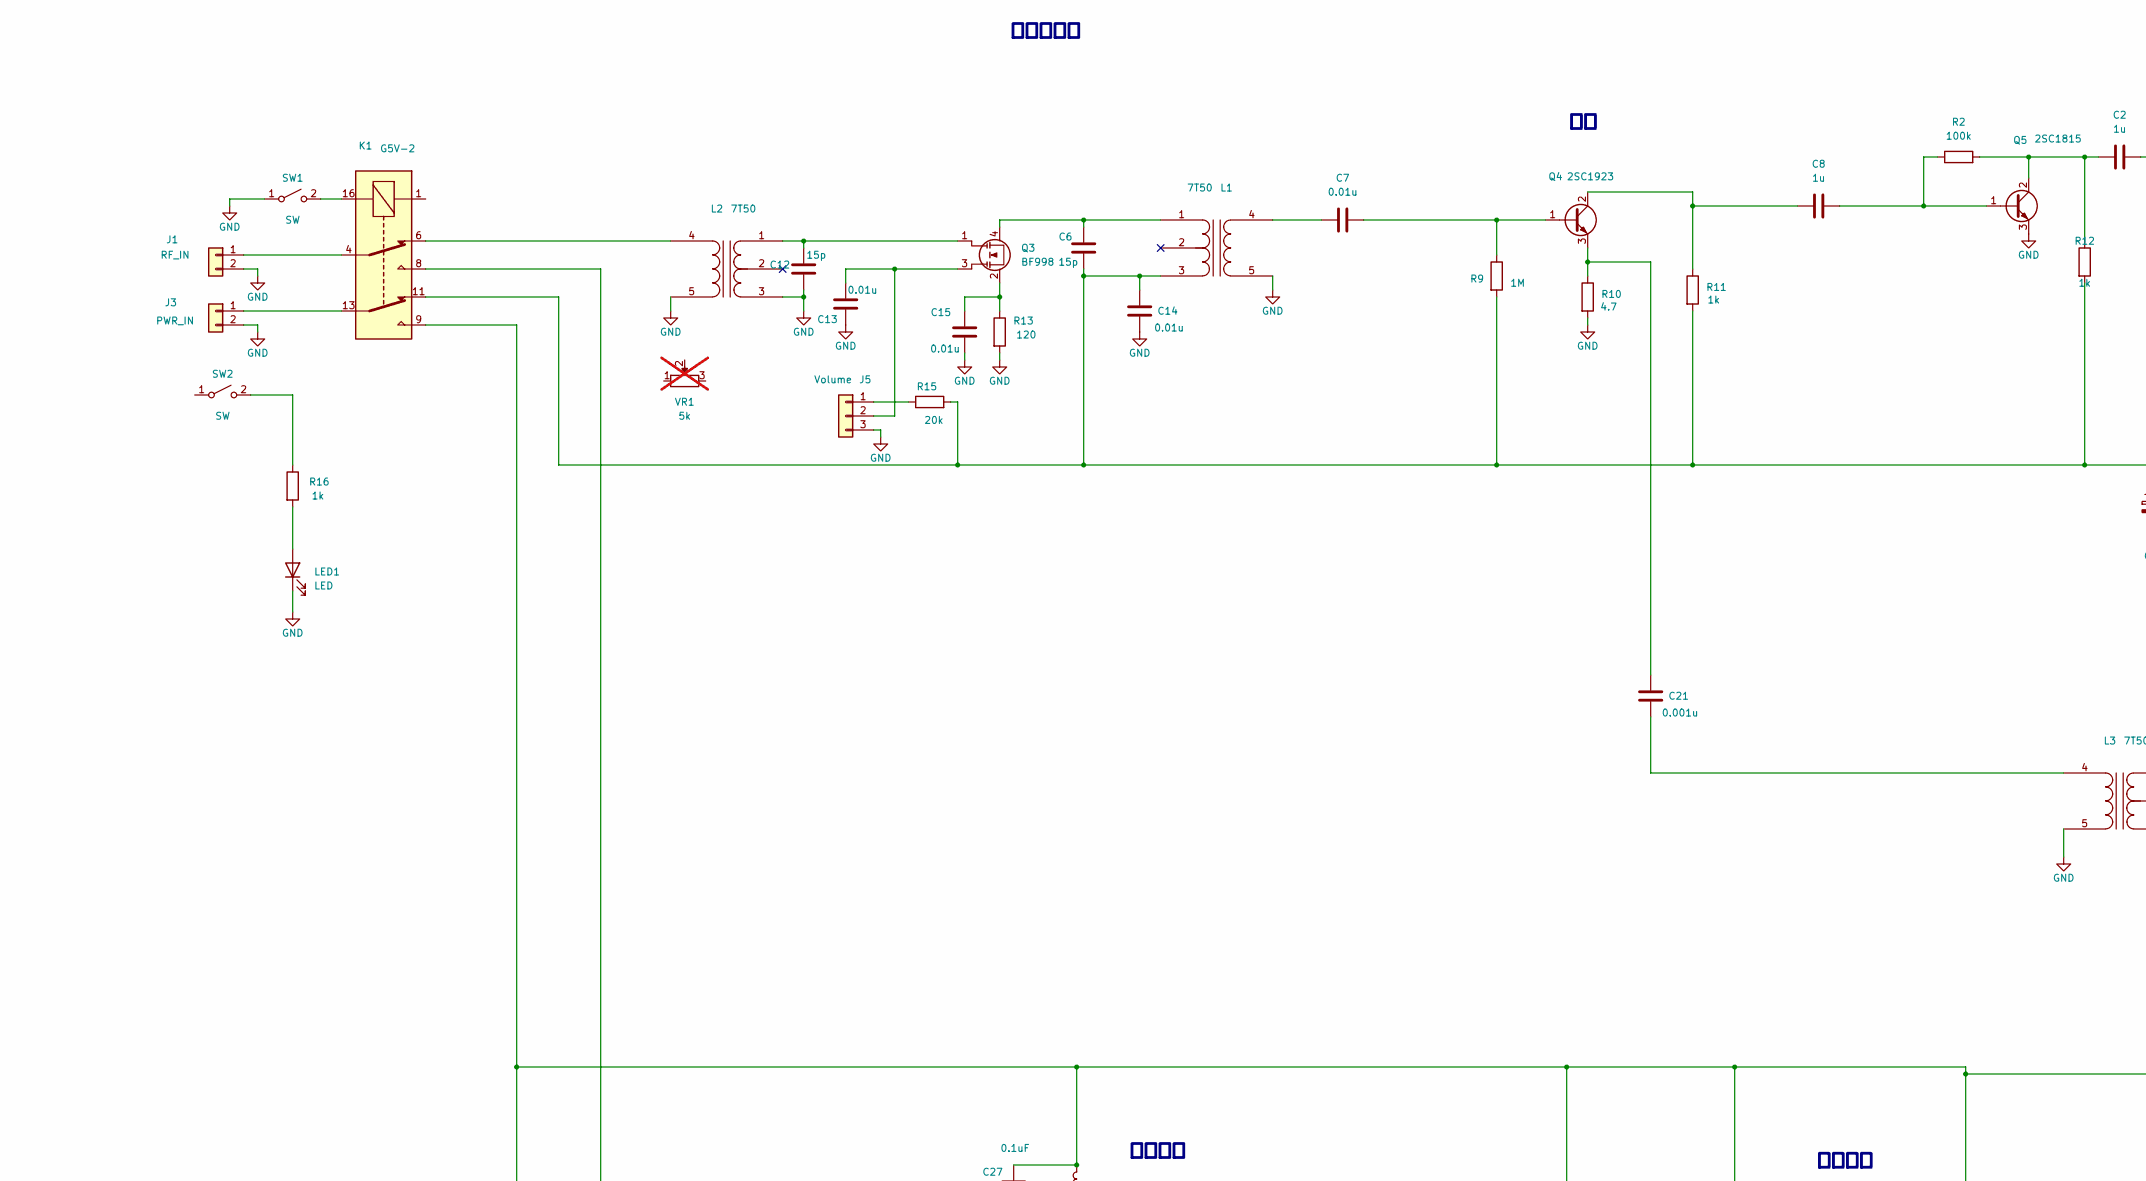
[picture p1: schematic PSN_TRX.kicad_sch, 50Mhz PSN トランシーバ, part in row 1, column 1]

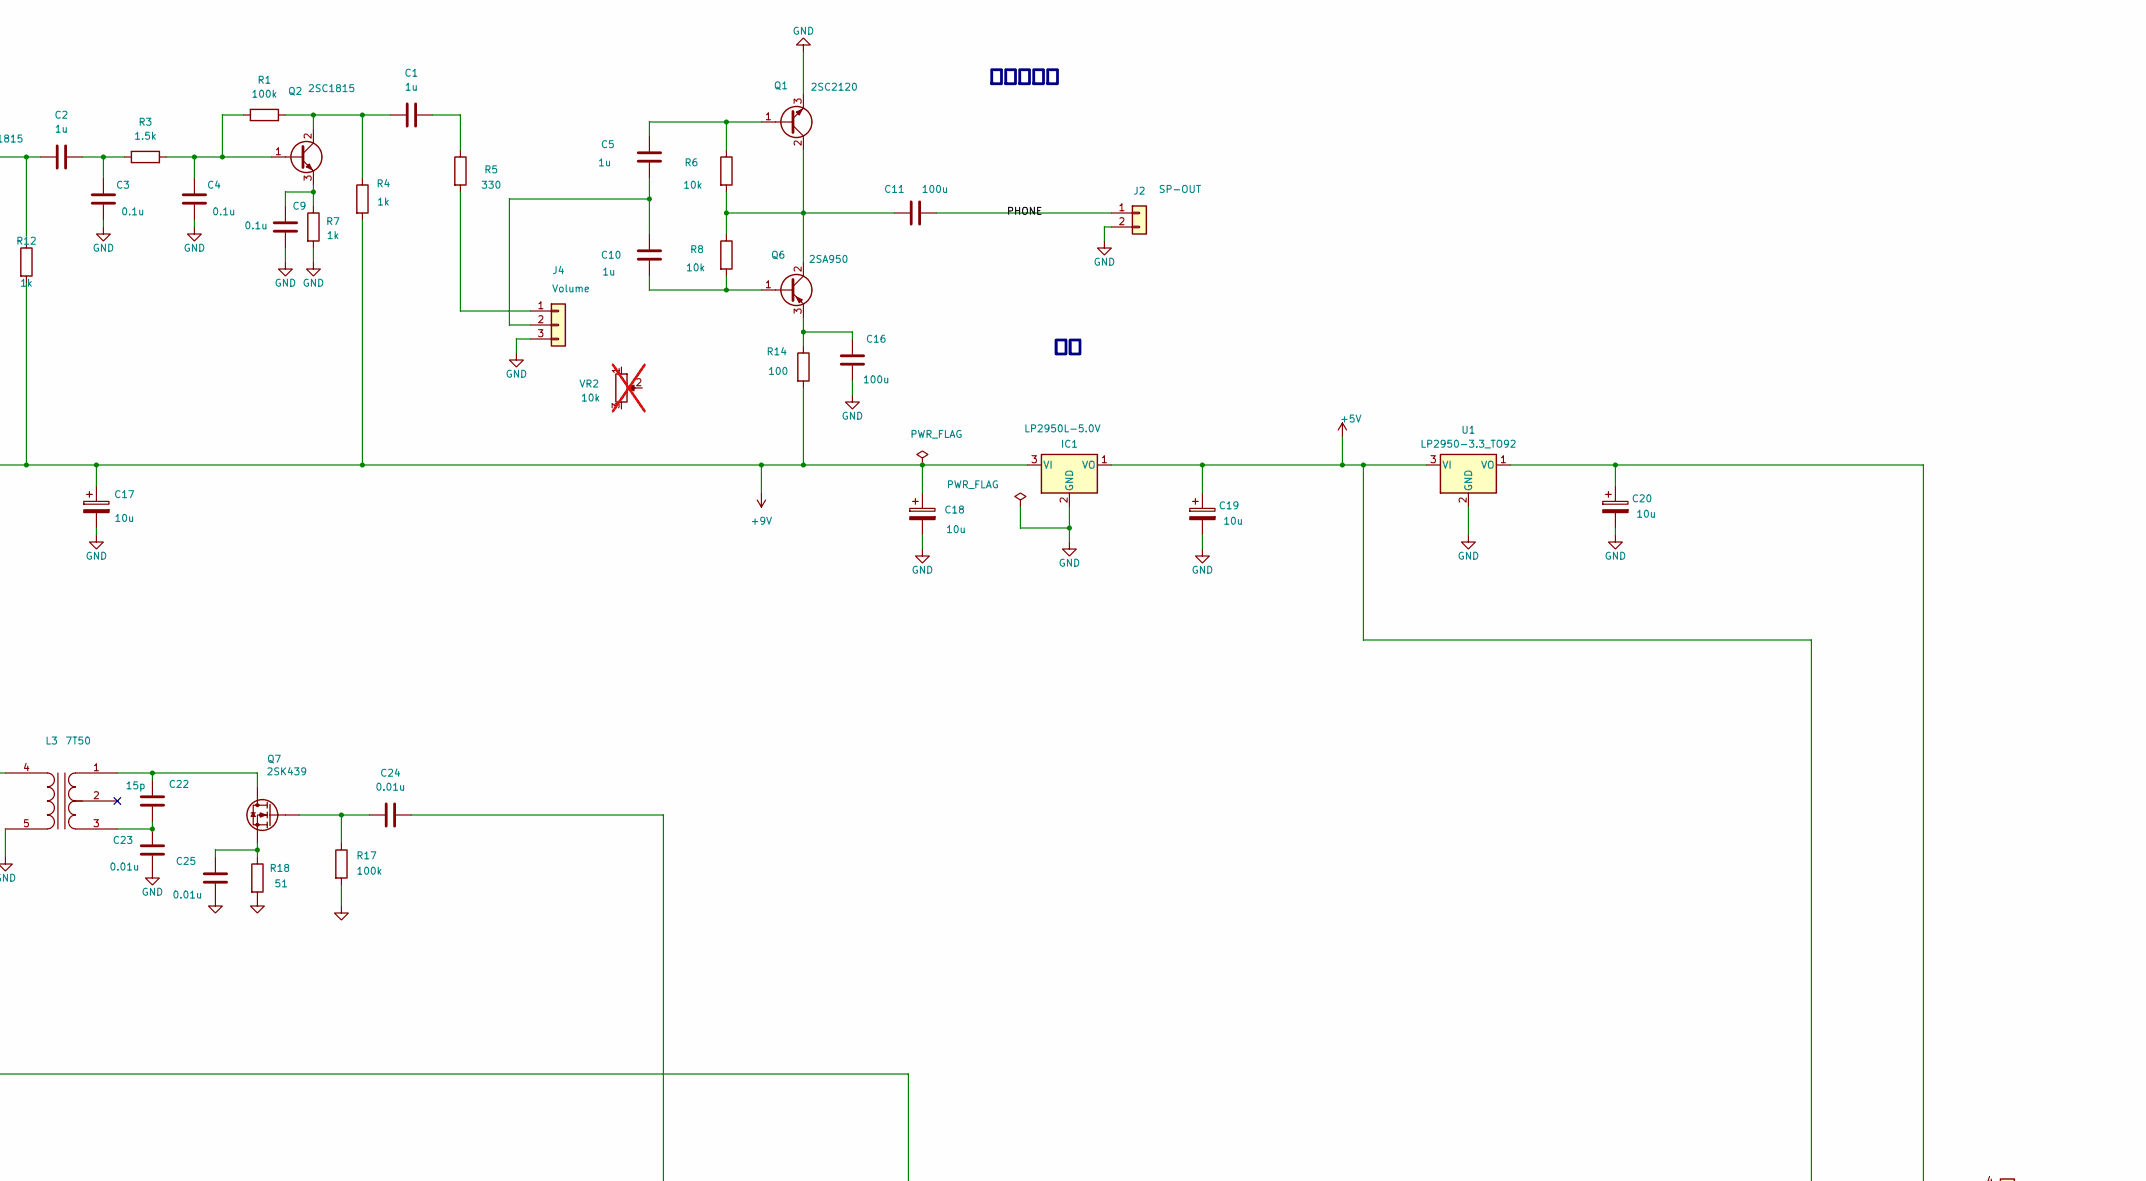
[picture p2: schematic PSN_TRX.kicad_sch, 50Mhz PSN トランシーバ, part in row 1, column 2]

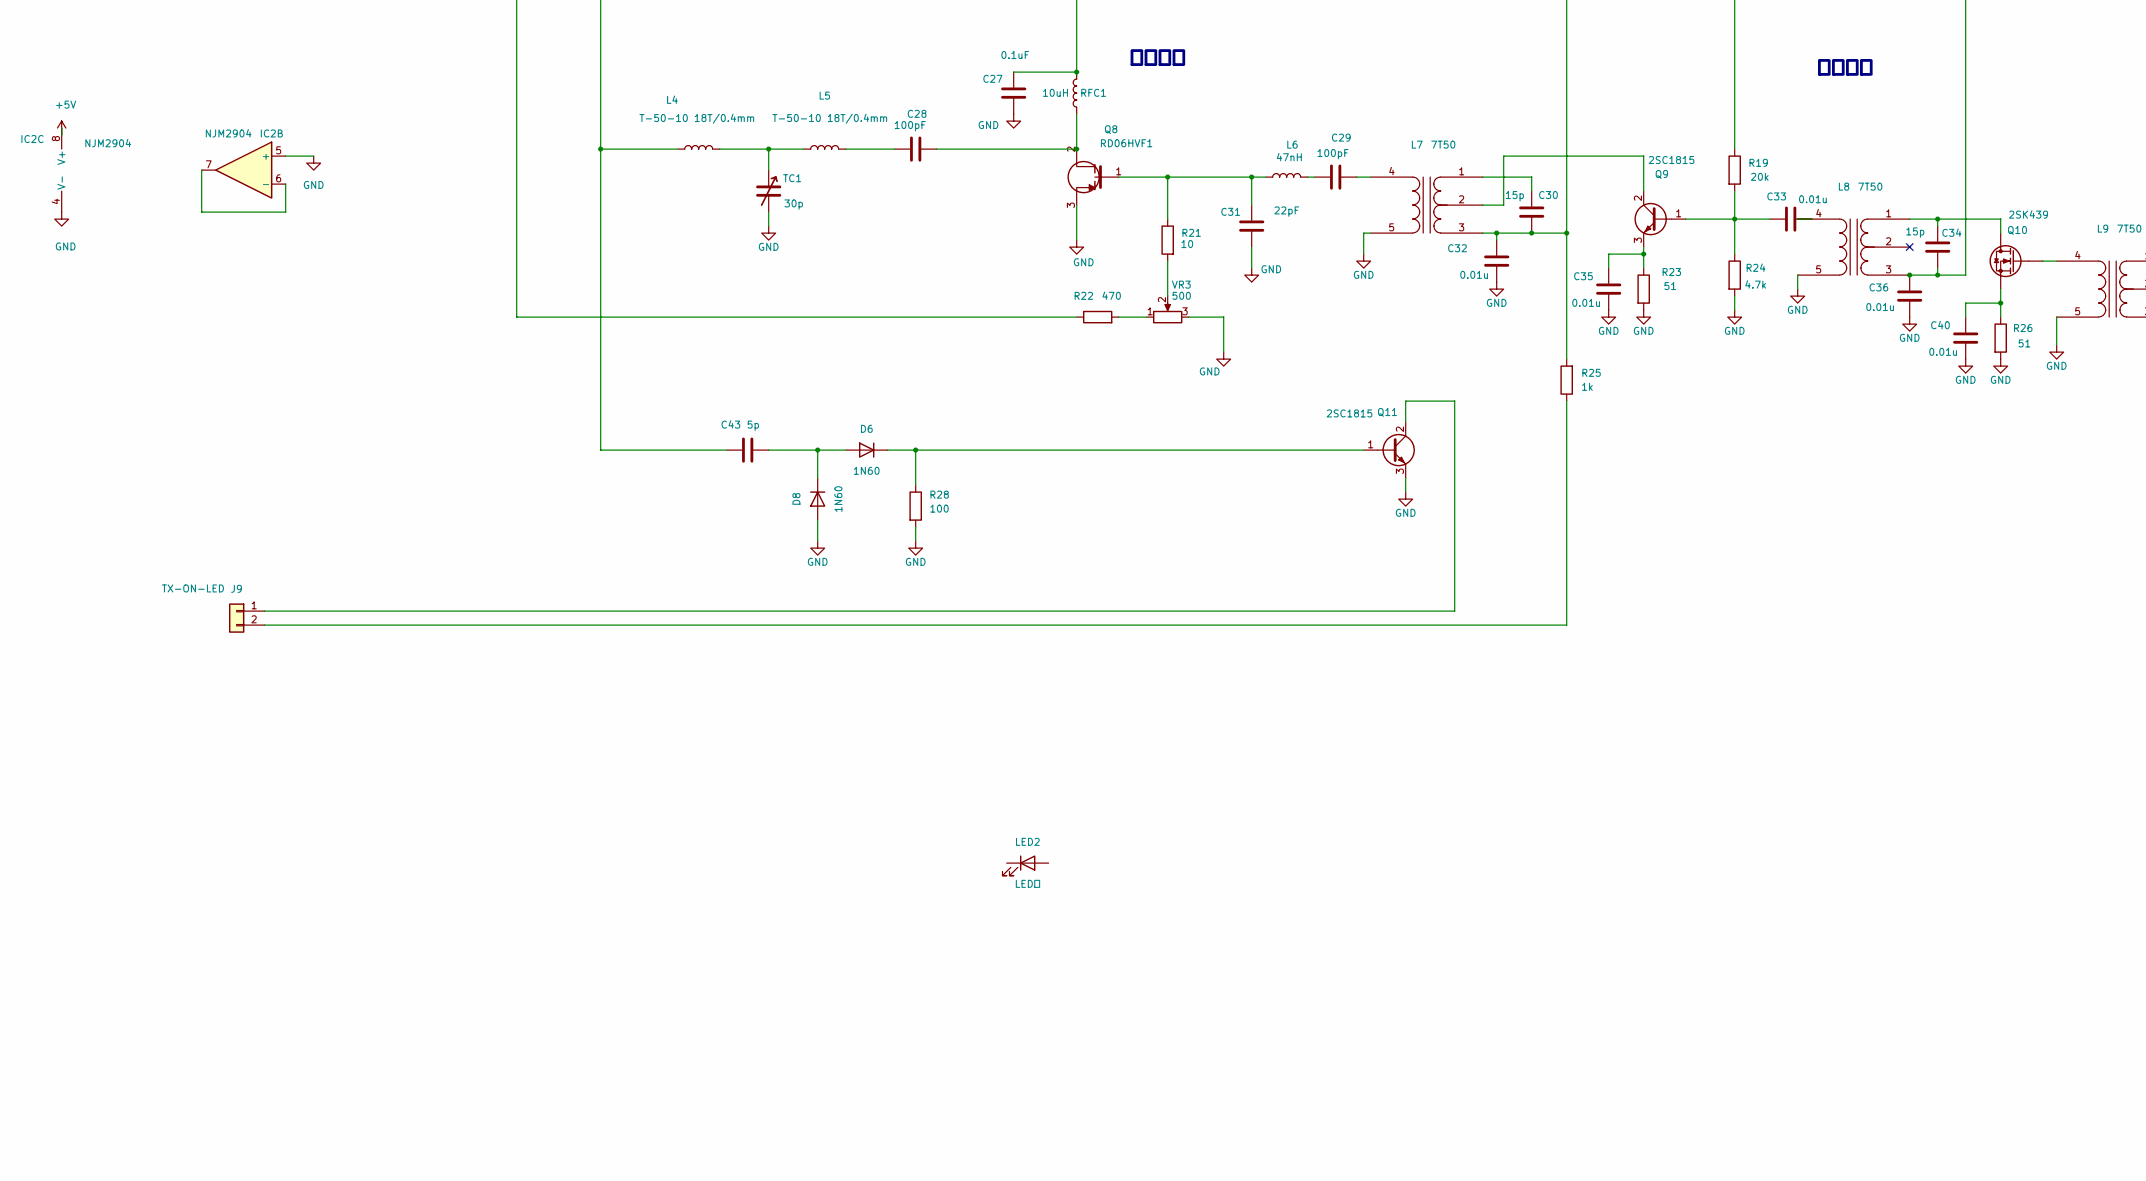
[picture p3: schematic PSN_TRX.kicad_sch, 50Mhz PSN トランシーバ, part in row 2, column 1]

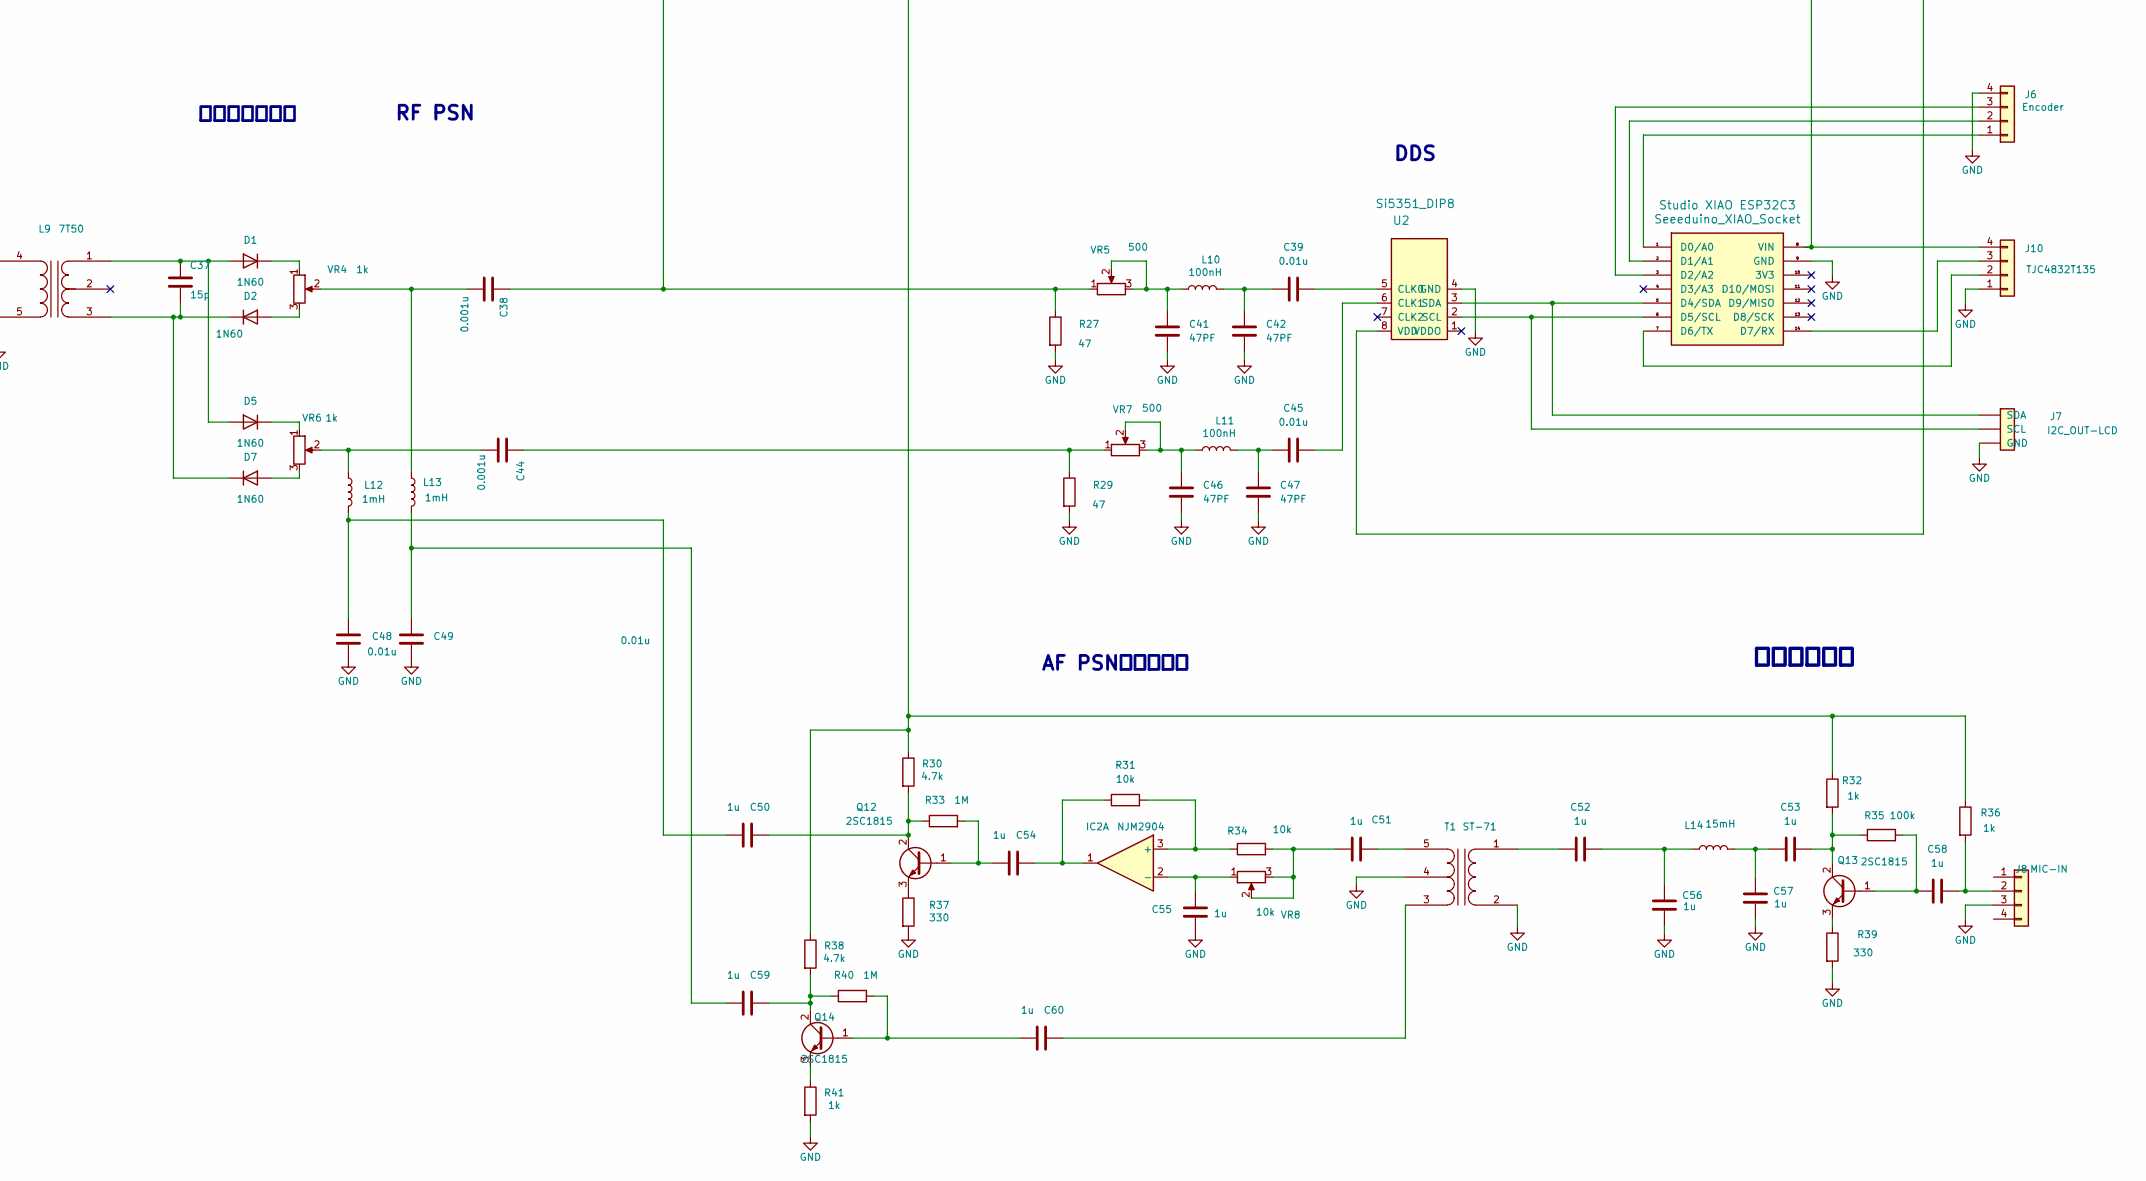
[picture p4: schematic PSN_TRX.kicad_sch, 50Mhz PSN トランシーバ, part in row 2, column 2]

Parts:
C1, C2, C5, C8, C10: 1u; C_Disc_D5.0mm_W2.5mm_P2.50mm
C3, C4, C9: 0.1u; C_Disc_D5.0mm_W2.5mm_P2.50mm
C6, C12, C22, C30, C34, C37: 15p; C_Disc_D3.0mm_W1.6mm_P2.50mm
C7, C13, C14, C15, C23, C24, C25, C32, C33, C35, C36, C39, C40, C45, C48, C49: 0.01u; C_Disc_D5.0mm_W2.5mm_P2.50mm
C11, C16: 100u; CP_Radial_D6.3mm_P2.50mm
C17, C18, C19, C20: 10u; CP_Radial_D5.0mm_P2.00mm
C21, C38, C44: 0.001u; C_Disc_D5.0mm_W2.5mm_P2.50mm
C27: 0.1uF; C_Disc_D5.0mm_W2.5mm_P5.00mm
C28, C29: 100pF; C_Disc_D5.0mm_W2.5mm_P5.00mm
C31: 22pF; C_Disc_D5.0mm_W2.5mm_P5.00mm
C41, C42, C46, C47: 47PF; C_Disc_D5.0mm_W2.5mm_P2.50mm
C43: 5p; C_Disc_D3.0mm_W1.6mm_P2.50mm
C50, C51, C52, C53, C54, C55, C56, C57, C58, C59, C60: 1u; CP_Radial_D5.0mm_P2.00mm
D1, D2, D5, D6, D7, D8: 1N60; D_DO-35_SOD27_P2.54mm_Vertical_CathodeUp
IC1: LP2950L-5.0V; TO-92_Inline
IC2: NJM2904; DIP-8_W7.62mm
J1: RF_IN; PinHeader_1x02_P2.54mm_Vertical
J2: SP-OUT; PinHeader_1x02_P2.54mm_Vertical
J3: PWR_IN; PinHeader_1x02_P2.54mm_Vertical
J4, J5: Volume; PinHeader_1x03_P2.54mm_Vertical
J6: Encoder; PinHeader_1x04_P2.54mm_Vertical
J7: I2C_OUT-LCD; PinHeader_1x03_P2.54mm_Vertical
J8: MIC-IN; PinHeader_1x04_P2.54mm_Vertical
J9: TX-ON-LED; PinHeader_1x02_P2.54mm_Vertical
J10: TJC4832T135; PinHeader_1x04_P2.54mm_Vertical
K1: G5V-2; Relay_DPDT_Omron_G5V-2
L1, L2, L3, L7, L8, L9: 7T50; L_FCZ07S_CT
L4, L5: T-50-10 18T/0.4mm; L_T50_2pin_Vertical
L6: 47nH; L_Axial_L9.5mm_D4.0mm_P12.70mm_Horizontal_Fastron_SMCC
L10, L11: 100nH; L_AL0510-153K_Vertical
L12, L13: 1mH; L_AL0510-153K_Vertical
L14: 15mH; L_AL0510-153K_Vertical
LED1: LED; PinHeader_1x02_P2.54mm_Vertical
LED2: LED黄; PinHeader_1x02_P2.54mm_Vertical
Q1: 2SC2120; TO-92_Inline
Q2, Q5, Q9, Q11, Q12, Q13, Q14: 2SC1815; TO-92_Inline
Q3: BF998; BF998_SOT143
Q4: 2SC1923; TO-92_Inline
Q6: 2SA950; TO-92_Inline
Q7, Q10: 2SK439; TO-92_Inline
Q8: RD06HVF1; TO-220-3_Vertical
R1, R2, R17, R35: 100k; R_Axial_DIN0207_L6.3mm_D2.5mm_P2.54mm_Vertical
R3: 1.5k; R_Axial_DIN0207_L6.3mm_D2.5mm_P2.54mm_Vertical
R4, R7, R11, R12, R16, R25, R32, R36, R41: 1k; R_Axial_DIN0207_L6.3mm_D2.5mm_P2.54mm_Vertical
R5, R37, R39: 330; R_Axial_DIN0207_L6.3mm_D2.5mm_P2.54mm_Vertical
R6, R8, R31, R34: 10k; R_Axial_DIN0207_L6.3mm_D2.5mm_P2.54mm_Vertical
R9, R33, R40: 1M; R_Axial_DIN0207_L6.3mm_D2.5mm_P2.54mm_Vertical
R10: 4.7; R_Axial_DIN0207_L6.3mm_D2.5mm_P2.54mm_Vertical
R13: 120; R_Axial_DIN0207_L6.3mm_D2.5mm_P2.54mm_Vertical
R14, R28: 100; R_Axial_DIN0207_L6.3mm_D2.5mm_P2.54mm_Vertical
R15, R19: 20k; R_Axial_DIN0207_L6.3mm_D2.5mm_P2.54mm_Vertical
R18, R23, R26: 51; R_Axial_DIN0207_L6.3mm_D2.5mm_P2.54mm_Vertical
R21: 10; R_Axial_DIN0207_L6.3mm_D2.5mm_P5.08mm_Vertical
R22: 470; R_Axial_DIN0207_L6.3mm_D2.5mm_P5.08mm_Vertical
R24, R30, R38: 4.7k; R_Axial_DIN0207_L6.3mm_D2.5mm_P2.54mm_Vertical
R27, R29: 47; R_Axial_DIN0207_L6.3mm_D2.5mm_P2.54mm_Vertical
RFC1: 10uH; L_Axial_L9.5mm_D4.0mm_P12.70mm_Horizontal_Fastron_SMCC
SW1, SW2: SW; SW_DIP_SPSTx01_Slide_6.7x4.1mm_W7.62mm_P2.54mm_LowProfile
Studio XIAO ESP32C3: Seeeduino_XIAO_Socket
T1: ST-71; Transformer_ST71_CB19
TC1: 30p; C_Trimmer_TMCV01
U1: LP2950-3.3_TO92; TO-92_Inline
U2: Si5351_DIP8; DIP-8_W7.62mm
VR1: 5k; Potentiometer_TOCOS_GF063P_Vertical; not fitted
VR2: 10k; Potentiometer_TOCOS_GF063P_Vertical; not fitted
VR3: 500; Potentiometer_Bourns_3266W_Vertical
VR4, VR6: 1k; Potentiometer_TOCOS_GF063P_Vertical
VR5, VR7: 500; Potentiometer_TOCOS_GF063P_Vertical
VR8: 10k; Potentiometer_TOCOS_GF063P_Vertical

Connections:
+5V: C19.1, IC1.1 (VO), IC2.8 (V+), J10.4, Studio XIAO ESP32C3.8 (VIN), U1.3 (VI)
+9V: C6.2, C14.1, C17.1, C18.1, IC1.3 (VI), K1.11, L1.3 (SB), R4.2, R9.2, R11.2, R12.2, R14.2, R15.2
/PHONE: C11.2, J2.1
GND: C3.2, C4.2, C9.2, C12.2, C13.2, C14.2, C15.2, C16.2, C17.2, C18.2, C19.2, C20.2, C23.2, C25.2, C27.2, C31.2, C32.2, C35.2, C36.2, C40.2, C41.1, C42.1, C46.1, C47.1, C48.2, C49.2, C55.2, C56.2, C57.2, D8.2 (A), IC1.2 (GND), IC2.4 (V-), IC2.5 (+), J1.2, J2.2, J3.2, J4.3, J5.3, J6.4, J7.3 (GND), J8.3, J10.1, L1.5 (AB), L2.3 (SB), L2.5 (AB), L3.5 (AB), L7.5 (AB), L8.5 (AB), L9.5 (AB), LED1.1 (K), Q1.3 (E), Q5.3 (E), Q8.3 (S), Q11.3 (E), R7.2, R10.2, R13.2, R17.2, R18.2, R23.2, R24.2, R26.2, R27.2, R28.2, R29.2, R37.2, R39.2, R41.2, SW1.1 (A), Studio XIAO ESP32C3.9 (GND), T1.2 (AB), T1.4 (SC), TC1.2, U1.2 (GND), U2.4 (GND), VR3.3
unnamed: C1.2, R5.1
unnamed: C2.2, C3.1, R3.1
unnamed: C24.2, C38.1, R27.1, VR5.1
unnamed: C28.2, L5.2
unnamed: C29.2, L6.1
unnamed: C38.2, L13.1, VR4.2
unnamed: C39.1, C42.2, L10.1
unnamed: C41.2, L10.2, VR5.2, VR5.3
unnamed: C43.1, K1.8, L4.1
unnamed: C44.1, R29.1, VR7.1
unnamed: C44.2, L12.1, VR6.2
unnamed: C45.1, C47.2, L11.1
unnamed: C46.2, L11.2, VR7.2, VR7.3
unnamed: C48.1, C50.1, L12.2
unnamed: C49.1, C59.1, L13.2
unnamed: C51.1, R34.2, VR8.2, VR8.3
unnamed: C52.2, C56.1, L14.1
unnamed: C53.1, C57.1, L14.2
unnamed: C54.2, IC2.1, R31.1
unnamed: C37.1, D1.2 (A), D5.2 (A), L9.1 (SA)
unnamed: D1.1 (K), VR4.1
unnamed: D2.2 (A), VR4.3
unnamed: C37.2, D2.1 (K), D7.1 (K), L9.3 (SB)
unnamed: D5.1 (K), VR6.1
unnamed: C43.2, D6.2 (A), D8.1 (K)
unnamed: D6.1 (K), Q11.1 (B), R28.1
unnamed: D7.2 (A), VR6.3
unnamed: IC2.3 (+), R31.2, R34.1
unnamed: C55.1, IC2.2 (-), VR8.1
unnamed: IC2.6 (-), IC2.7
unnamed: J1.1, K1.4
unnamed: J3.1, K1.13
unnamed: J4.1, R5.2
unnamed: C5.1, C10.2, J4.2
unnamed: J5.1, R15.1
unnamed: C13.1, J5.2, Q3.3 (G2)
unnamed: J6.1, Studio XIAO ESP32C3.1 (D0/A0)
unnamed: J6.2, Studio XIAO ESP32C3.2 (D1/A1)
unnamed: J6.3, Studio XIAO ESP32C3.3 (D2/A2)
unnamed: J7.2 (SCL), Studio XIAO ESP32C3.6 (D5/SCL), U2.2 (SCL)
unnamed: J7.1 (SDA), Studio XIAO ESP32C3.5 (D4/SDA), U2.3 (SDA)
unnamed: C58.2, J8.2, R36.2
unnamed: J9.1, Q11.2 (C)
unnamed: J9.2, R25.1
unnamed: J10.2, Studio XIAO ESP32C3.7 (D6/TX)
unnamed: J10.3, Studio XIAO ESP32C3.14 (D7/RX)
unnamed: K1.16, SW1.2 (B)
unnamed: C7.1, L1.4 (AA)
unnamed: C6.1, L1.1 (SA), Q3.4 (D)
unnamed: K1.6, L2.4 (AA)
unnamed: C12.1, L2.1 (SA), Q3.1 (G1)
unnamed: C21.2, L3.4 (AA)
unnamed: C22.1, L3.1 (SA), Q7.2 (D)
unnamed: C22.2, C23.1, L3.3 (SB)
unnamed: L4.2, L5.1, TC1.1
unnamed: C29.1, L7.4 (AA)
unnamed: L7.2 (CT), Q9.2 (C)
unnamed: C30.1, L7.1 (SA)
unnamed: C27.1, C30.2, C32.1, C34.2, C36.1, K1.9, L7.3 (SB), L8.3 (SB), R19.1, R22.1, R25.2, R30.1, R32.1, R36.1, R38.1, RFC1.1
unnamed: C33.2, L8.4 (AA)
unnamed: C34.1, L8.1 (SA), Q10.2 (D)
unnamed: L9.4 (AA), Q10.1 (G)
unnamed: LED1.2 (A), R16.2
unnamed: C5.2, Q1.1 (B), R6.1
unnamed: C11.1, Q1.2 (C), Q6.2 (C), R6.2, R8.1
unnamed: C4.1, Q2.1 (B), R1.1, R3.2
unnamed: C1.1, Q2.2 (C), R1.2, R4.1
unnamed: C9.1, Q2.3 (E), R7.1
unnamed: C15.1, Q3.2 (S), R13.1
unnamed: C7.2, Q4.1 (B), R9.1
unnamed: C8.1, Q4.2 (C), R11.1
unnamed: C21.1, Q4.3 (E), R10.1
unnamed: C8.2, Q5.1 (B), R2.1
unnamed: C2.1, Q5.2 (C), R2.2, R12.1
unnamed: C10.1, Q6.1 (B), R8.2
unnamed: C16.1, Q6.3 (E), R14.1
unnamed: C24.1, Q7.1 (G), R17.1
unnamed: C25.1, Q7.3 (S), R18.1
unnamed: C28.1, Q8.2 (D), RFC1.2
unnamed: C31.1, L6.2, Q8.1 (G), R21.1
unnamed: C33.1, Q9.1 (B), R19.2, R24.1
unnamed: C35.1, Q9.3 (E), R23.1
unnamed: C40.1, Q10.3 (S), R26.1
unnamed: C54.1, Q12.1 (B), R33.2
unnamed: C50.2, Q12.2 (C), R30.2, R33.1
unnamed: Q12.3 (E), R37.1
unnamed: C58.1, Q13.1 (B), R35.2
unnamed: C53.2, Q13.2 (C), R32.2, R35.1
unnamed: Q13.3 (E), R39.1
unnamed: C60.1, Q14.1 (B), R40.2
unnamed: C59.2, Q14.2 (C), R38.2, R40.1
unnamed: Q14.3 (E), R41.1
unnamed: R16.1, SW2.2 (B)
unnamed: R21.2, VR3.2
unnamed: R22.2, VR3.1
unnamed: C52.1, T1.1 (AA)
unnamed: C60.2, T1.3 (SA)
unnamed: C51.2, T1.5 (SB)
unnamed: C20.1, U1.1 (VO), U2.8 (VDD)
unnamed: C39.2, U2.5 (CLK0)
unnamed: C45.2, U2.6 (CLK1)

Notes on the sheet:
合成・平衡変調
DDS
低周波増幅
AF PSN・信号分割
RF PSN
高周波増幅
終段増幅
励振増幅
マイクアンプ

Board: 4 copper layers, 157 parts (0 on the bottom side), 102 nets, no tracks yet.

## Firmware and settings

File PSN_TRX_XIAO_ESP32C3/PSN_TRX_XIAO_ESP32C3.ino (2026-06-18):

/*
 * PSN TRX VFO - Seeed Studio XIAO ESP32C3 (RISC-V 32-bit 160MHz) + Si5351
 * 50.000 ~ 51.000 MHz (6m Band)
 *
 * ---- コンパイル時ディスプレイ選択 ----
 *   #define USE_TJC_DISPLAY  → TJC4832T135  Serial1: D6(TX) D7(RX)
 *   コメントアウト           → SSD1306 OLED I2C: D4(SDA) D5(SCL)
 *
 * ---- TJC HMI 画面構成 (TJC USART HMI Editor で作成) ----
 *   t0 : 周波数表示  (大テキスト)
 *   t1 : ステップ表示
 *   t2 : 固定情報    (TJC_FIXED_LINE1 / LINE2 で内容を指定)
 *
 * Libraries:
 *   - Etherkit Si5351
 *   - Adafruit SSD1306 / Adafruit GFX  (OLED使用時のみ必要)
 *   - Preferences  (ESP32 標準内蔵・NVS フラッシュ保存)
 *
 * Wiring (XIAO ESP32C3):
 *   Si5351 SDA  -> D4 (GPIO6)
 *   Si5351 SCL  -> D5 (GPIO7)
 *   OLED  SDA   -> D4 (GPIO6)   ※ OLED使用時
 *   OLED  SCL   -> D5 (GPIO7)   ※ OLED使用時
 *   Encoder A   -> D0 (GPIO2)
 *   Encoder B   -> D1 (GPIO3)
 *   Encoder SW  -> D2 (GPIO4)
 *   TJC TX      -> D6 (GPIO21)  ※ TJC使用時
 *   TJC RX      -> D7 (GPIO20)  ※ TJC使用時
 */

// ============================================================
// ★ ここを編集してディスプレイを選択
// ============================================================
#define USE_TJC_DISPLAY

// TJC固定表示文字列（内容未定のため仮。確定後に変更）
#define TJC_FIXED_LINE1  "6m PSN TRX"
#define TJC_FIXED_LINE2  ""
// ============================================================

#include <Wire.h>
#include <si5351.h>
#include <Preferences.h>

#ifndef USE_TJC_DISPLAY
  #include <Adafruit_GFX.h>
  #include <Adafruit_SSD1306.h>
  #define SCREEN_WIDTH  128
  #define SCREEN_HEIGHT  64
  Adafruit_SSD1306 oled(SCREEN_WIDTH, SCREEN_HEIGHT, &Wire, -1);
#endif

// ---- Si5351 ----
Si5351 si5351;

// ---- Preferences (NVS) ----
Preferences prefs;

// ---- Rotary Encoder ----
#define ENC_A  D0
#define ENC_B  D1
#define ENC_SW D2

// ---- 周波数設定 ----
#define FREQ_MIN     50000000L
#define FREQ_MAX     51000000L
#define FREQ_DEFAULT 50500000L

long currentFreq = FREQ_DEFAULT;

// ---- ステップ ----
const long  stepValues[] = {10, 100, 1000, 10000, 100000};
const char* stepLabels[] = {"10Hz", "100Hz", "1kHz", "10kHz", "100kHz"};
const int   stepCount    = 5;
int stepIndex = 2;

// ---- エンコーダ ----
volatile int encCount  = 0;
int          lastCount = 0;

// ---- ボタン ----
bool          lastBtnState = HIGH;
unsigned long lastBtnTime  = 0;

// ---- ISR ----
void IRAM_ATTR encoderISR() {
  static int lastA = HIGH;
  int a = digitalRead(ENC_A);
  int b = digitalRead(ENC_B);
  if (a != lastA) {
    encCount += (b != a) ? 1 : -1;
    lastA = a;
  }
}

// ---- Si5351 二相出力 ----
#define QUAD_DIV 16

void setFrequency(long freq) {
  uint64_t f   = (uint64_t)freq * 100ULL;
  uint64_t pll = f * QUAD_DIV;
  si5351.set_freq_manual(f, pll, SI5351_CLK0);
  si5351.set_freq_manual(f, pll, SI5351_CLK1);
  si5351.set_phase(SI5351_CLK0, 0);
  si5351.set_phase(SI5351_CLK1, QUAD_DIV / 4);
  si5351.pll_reset(SI5351_PLLA);
}

// ============================================================
// TJC4832T135 ドライバ
// ============================================================
#ifdef USE_TJC_DISPLAY

void tjcSend(const char* cmd) {
  Serial1.print(cmd);
  Serial1.write(0xFF);
  Serial1.write(0xFF);
  Serial1.write(0xFF);
}

void tjcSetText(const char* component, const char* value) {
  char buf[80];
  snprintf(buf, sizeof(buf), "%s.txt=\"%s\"", component, value);
  tjcSend(buf);
}

void tjcInit() {
  // ESP32C3: D6=GPIO21(TX), D7=GPIO20(RX)
  Serial1.begin(9600, SERIAL_8N1, D7, D6);
  delay(500);
  tjcSend("baud=9600");
  tjcSend("page 0");
  char fixed[48];
  if (strlen(TJC_FIXED_LINE2) > 0)
    snprintf(fixed, sizeof(fixed), "%s  %s", TJC_FIXED_LINE1, TJC_FIXED_LINE2);
  else
    snprintf(fixed, sizeof(fixed), "%s", TJC_FIXED_LINE1);
  tjcSetText("t2", fixed);
}

void updateDisplay() {
  long f   = currentFreq;
  int  mhz = f / 1000000;
  int  khz = (f % 1000000) / 1000;
  int  hz  = f % 1000;

  char freqBuf[24];
  snprintf(freqBuf, sizeof(freqBuf), "%d.%03d.%03d MHz", mhz, khz, hz);
  tjcSetText("t0", freqBuf);

  char stepBuf[20];
  snprintf(stepBuf, sizeof(stepBuf), "STEP: %s", stepLabels[stepIndex]);
  tjcSetText("t1", stepBuf);
}

// ============================================================
// SSD1306 OLED ドライバ
// ============================================================
#else

void updateDisplay() {
  oled.clearDisplay();
  oled.setTextSize(2);
  oled.setTextColor(SSD1306_WHITE);
  oled.setCursor(0, 4);

  long f   = currentFreq;
  int  mhz = f / 1000000;
  int  khz = (f % 1000000) / 1000;
  int  hz  = f % 1000;

  char buf[24];
  sprintf(buf, "%2d.%03d.%03d", mhz, khz, hz);
  oled.print(buf);

  oled.setTextSize(1);
  oled.setCursor(108, 10);
  oled.print("MHz");

  oled.drawLine(0, 28, 127, 28, SSD1306_WHITE);

  oled.setTextSize(1);
  oled.setCursor(0, 34);
  oled.print("STEP: ");
  oled.print(stepLabels[stepIndex]);

  oled.setCursor(0, 50);
  oled.print("50MHz Band  6m");

  oled.display();
}

#endif  // USE_TJC_DISPLAY

// ---- NVS 保存 ----
void saveFreq() {
  prefs.begin("psn_trx", false);
  prefs.putLong("freq", currentFreq);
  prefs.putInt("step", stepIndex);
  prefs.end();
}

// ---- NVS 読み込み ----
void loadFreq() {
  prefs.begin("psn_trx", true);
  currentFreq = prefs.getLong("freq", FREQ_DEFAULT);
  stepIndex   = prefs.getInt("step", 2);
  prefs.end();

  if (currentFreq < FREQ_MIN || currentFreq > FREQ_MAX)
    currentFreq = FREQ_DEFAULT;
  if (stepIndex < 0 || stepIndex >= stepCount)
    stepIndex = 2;
}

// ============================================================
void setup() {
  Serial.begin(115200);

  pinMode(ENC_A,  INPUT_PULLUP);
  pinMode(ENC_B,  INPUT_PULLUP);
  pinMode(ENC_SW, INPUT_PULLUP);
  attachInterrupt(digitalPinToInterrupt(ENC_A), encoderISR, CHANGE);

  Wire.begin();

#ifdef USE_TJC_DISPLAY
  tjcInit();
#else
  if (!oled.begin(SSD1306_SWITCHCAPVCC, 0x3C))
    Serial.println("OLED not found");
  oled.clearDisplay();
  oled.setTextColor(SSD1306_WHITE);
  oled.setTextSize(1);
  oled.setCursor(20, 28);
  oled.print("PSN TRX VFO");
  oled.display();
  delay(1000);
#endif

  if (!si5351.init(SI5351_CRYSTAL_LOAD_8PF, 25000000, 0))
    Serial.println("Si5351 not found");
  si5351.drive_strength(SI5351_CLK0, SI5351_DRIVE_8MA);
  si5351.drive_strength(SI5351_CLK1, SI5351_DRIVE_8MA);
  si5351.output_enable(SI5351_CLK2, 0);

  loadFreq();
  setFrequency(currentFreq);
  updateDisplay();
}

// ============================================================
void loop() {
  int cnt = encCount;
  if (cnt != lastCount) {
    int diff = cnt - lastCount;
    currentFreq += (long)diff * stepValues[stepIndex];
    if (currentFreq < FREQ_MIN) currentFreq = FREQ_MIN;
    if (currentFreq > FREQ_MAX) currentFreq = FREQ_MAX;
    lastCount = cnt;
    setFrequency(currentFreq);
    updateDisplay();
    saveFreq();
  }

  bool btn = digitalRead(ENC_SW);
  if (btn == LOW && lastBtnState == HIGH) {
    unsigned long now = millis();
    if (now - lastBtnTime > 200) {
      stepIndex = (stepIndex + 1) % stepCount;
      updateDisplay();
      saveFreq();
      lastBtnTime = now;
    }
  }
  lastBtnState = btn;

  delay(1);
}

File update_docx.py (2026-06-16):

from docx import Document

# docx ファイルを開く
doc = Document("/Users/kazuichishinjo/Desktop/PSN_TRX_Nano_R4/docs/PSN_TRX_VFO改造仕様書.docx")

# 置換のペアリスト
replacements = [
    ("ESP32", "Arduino Nano R4"),
    ("GPIO21", "A4"),
    ("GPIO22", "A5"),
    ("GPIO32", "D2"),
    ("GPIO33", "D3"),
    ("GPIO25", "D4"),
    ("Preferences", "EEPROM"),
    ("NVS", "EEPROM"),
    ("IRAM_ATTR", ""),
    ("SDA=21, SCL=22", "A4=SDA, A5=SCL"),
    ("SDA  -> GPIO21", "SDA  -> A4"),
    ("SCL  -> GPIO22", "SCL  -> A5"),
    ("Encoder A   -> GPIO32", "Encoder A   -> D2"),
    ("Encoder B   -> GPIO33", "Encoder B   -> D3"),
    ("Encoder SW  -> GPIO25", "Encoder SW  -> D4"),
]

# 全段落と実行内容の置換処理
for paragraph in doc.paragraphs:
    for old, new in replacements:
        if old in paragraph.text:
            for run in paragraph.runs:
                if old in run.text:
                    run.text = run.text.replace(old, new)

# テーブル内のテキストも置換
for table in doc.tables:
    for row in table.rows:
        for cell in row.cells:
            for paragraph in cell.paragraphs:
                for old, new in replacements:
                    if old in paragraph.text:
                        for run in paragraph.runs:
                            if old in run.text:
                                run.text = run.text.replace(old, new)

# 保存
doc.save("/Users/kazuichishinjo/Desktop/PSN_TRX_Nano_R4/docs/PSN_TRX_VFO改造仕様書.docx")
print("docx file updated successfully!")

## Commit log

2026-06-15 Initial commit: ESP32+Si5351 VFO for PSN SSB TRX
    - PSN_TRX_ESP32.ino: VFO sketch with quadrature CLK0/CLK1 output
    - 50.000-51.000 MHz tunable, OLED display, NVS frequency memory
    - docs: 改造仕様書 (modification spec with PA circuit)
2026-06-15 Add KiCad schematic and PCB data
    - PSN_TRX.kicad_sch: Full PSN SSB TRX schematic
    - PSN_TRX.kicad_pcb: PCB layout
    - PSN_TRX.kicad_sym: Custom symbols
    - PSN_TRX.pretty/: Custom footprints (T30/T50 toroids, TMCV01, FCZ07S, ST71)
    - BOM.md / bom.csv: Bill of materials
    [PSN_TRX.kicad_pcb, PSN_TRX.kicad_sch, bom.csv]
2026-06-15 Arduino Nano R4 移植 & KiCad ライブラリ統合
    - Arduino Nano R4 (Renesas RA4M1) への移植完了
    * スケッチ: ESP32 → Nano R4 対応に変更
    * GPIO ピン: 再割り当て (GPIO21/22 → A4/A5 など)
    * ストレージ: Preferences → EEPROM に変更
    * リポジトリ名: PSN_TRX_ESP32 → PSN_TRX_Nano_R4
    - KiCad シンボル・フットプリント作成
    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
    [PSN_TRX.kicad_sch, bom.csv]
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2026-06-15 J5 I2C_OUT コネクタ（3ピン）を追加
    - Arduino Nano R4 の A4（SDA）、A5（SCL）から I2C 出力コネクタを実装
    - J5: 3ピンコネクタ（SDA/SCL/GND）
    - フットプリント: Connector_PinHeader_2.54mm:PinHeader_1x03_P2.54mm_Vertical
    - シンボル: PSN_TRX:I2C_OUT カスタムシンボル
    - スケマティクスに配線完了
    [PSN_TRX.kicad_sch]
2026-06-15 スケマティクス更新（KiCad 再起動後の反映）
    - J5 I2C_OUT シンボル表示を PSN_TRX:I2C_OUT に更新
    - キャッシュクリア後の最終確認
    [PSN_TRX.kicad_sch]
2026-06-15 Fix library paths for macOS compatibility
    Windows絶対パスを${KIPRJMOD}相対パスに変更。
    未使用のArduino外部ライブラリエントリを削除。
    [PSN_TRX.kicad_sch]
2026-06-15 Update schematic (KiCad auto-modified junctions)
    [PSN_TRX.kicad_sch]
2026-06-15 Update docx: replace ESP32 terms with Arduino Nano R4
2026-06-16 KiCadシンボル・フットプリント追加、ERC修正
    - AE_LCNV4_MOSFET.kicad_sym 新規作成（秋月AE-LCNV4-MOSFET 4chレベルシフタ）
    - DIP-12_W7.62mm.kicad_mod 新規作成（DIP-12フットプリント）
    - sym-lib-table に AE_LCNV4_MOSFET ライブラリ登録
    - Si5351_DIP8 VDD(8番)ピンを power_in → passive に変更（ERC修正）
    - AE-LCNV4-MOSFET HV(4番)/GND(3,10番)/LV(9番)を power_in → passive に変更（ERC修正）
    - Arduino_Nano_R4_Socket 3.3V(16番)ピンを passive → power_out に変更
    [PSN_TRX.kicad_sch]
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2026-06-16 KiCad: シンボル統合・パネル部品除外・PCBクリーンアップ
    - 外部シンボルファイル4本をPSN_TRX.kicad_symに統合
    (Arduino_Nano_R4_Socket, Si5351_DIP8, Si5351A, AE-LCNV4-MOSFET)
    → sym-lib-tableはPSN_TRXライブラリのみに統一
    - SW1, SW2, R13, LED1をon_board=noに変更（パネル取付部品）
    - PCBからSW1, R13, LED1フットプリントを削除（SW2は元から未配置）
    - .gitignoreに_restore_backup_*/を追加
    [PSN_TRX.kicad_pcb, PSN_TRX.kicad_sch]
2026-06-16 transceiver: PSN型SSBトランシーバー全体回路図を追加
    kazushinjo/PSN_TRX_New から移植:
    - KiCadプロジェクトファイル一式 (kicad_sch/pcb/pro/sym/net)
    - フットプリントライブラリ (PSN_TRX.pretty/)
    - 部品表 (bom.csv, BOM.md)
    - 回路図生成・配置スクリプト (scripts/*.py)
    - sym-lib-table / fp-lib-table
    [PSN_TRX.kicad_pcb, PSN_TRX.kicad_sch, bom.csv]
2026-06-16 KiCad: VR1・VR2をパネル取付に変更（on_board=no、PCBから削除）
    [PSN_TRX.kicad_pcb, PSN_TRX.kicad_sch]
2026-06-16 fix: exclude VR1/VR2 from PCB update (on_board no)
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2026-06-16 feat: assign GF063P footprint to VR3-VR7
    [PSN_TRX.kicad_sch]
2026-06-16 feat: assign GF063P footprint to VR3-VR5
    [PSN_TRX.kicad_sch]
2026-06-16 fix: exclude VR1/VR2 from footprint assignment, use GF063P for VR3-VR7
2026-06-16 fix: VR1/VR2 on_board=no, VR3-VR5 GF063P footprint in schematic generator
2026-06-16 fix: VR1/VR2 を DNP・NO board に設定（in_bom/on_board/in_pos_files=no, dnp=yes）
    [PSN_TRX.kicad_sch]
2026-06-16 fix: VR1/VR2 フットプリントをGF063Pに統一、DNP/NO board設定
    - VR1/VR2: Connector_PinHeader → PSN_TRX:Potentiometer_TOCOS_GF063P_Vertical
    - VR1/VR2: in_bom/on_board/in_pos_files=no, dnp=yes
    [PSN_TRX.kicad_sch]
2026-06-16 feat: GF063Pポテンショメータのカスタムシンボル追加・フットプリント修正、VR3-7をPSN_TRXライブラリに移行
    - PSN_TRX:Potentiometer_GF063P シンボルをシンボルライブラリに追加（VRプレフィックス、フットプリント紐付け済み）
    - Potentiometer_TOCOS_GF063P_Vertical フットプリントのピン配置をデータシートに基づき修正
    - 旧: ピン1・2・3が一直線（誤り）
    - 新: 三角配置（ピン2ワイパーを2.5mm上方にオフセット）
    - VR3〜VR7のシンボル参照を Device:R_Potentiometer → PSN_TRX:Potentiometer_GF063P に変更
    [PSN_TRX.kicad_pcb, PSN_TRX.kicad_sch]
2026-06-16 docs: VFO改造仕様書をArduino Nano R4向けに更新、update_docx.pyのパスをmacOS用に修正
    [update_docx.py]
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2026-06-17 fix: kicad_symからセミコロンコメントを削除（KiCad S式非対応）
2026-06-17 feat: J8ロータリーエンコーダ用4ピンコネクタを回路図に追加
    Conn_01x04: ENC_A(D0), ENC_B(D1), ENC_SW(D2), GND
    [PSN_TRX.kicad_sch]
2026-06-17 fix: J8を3ピン(Conn_01x03)から4ピン(Conn_01x04)に変更、重複エントリを削除
    [PSN_TRX.kicad_sch]
2026-06-17 chore: PSN_TRX.net（ネットリスト）を削除
    [1W_PA.kicad_sch, PSN_TRX.kicad_sch]
2026-06-17 refactor: 回路図の部品番号を全タイプ1から連番に振り直し
    位置座標(上→下/左→右)でソートして各タイプを1から採番
    A,C,D,IC,J,K,L,LED,Q,R,RFC,SW,T,TC,U,VR 全16タイプ 149件更新
    [PSN_TRX.kicad_sch]
2026-06-17 fix: RFC1・L6のフットプリントをKiCad 10対応名に更新
    L_Axial_L9.0mm_D4.0mm_P12.5mm_Horizontal_RM12.5mm
    → L_Axial_L9.5mm_D4.0mm_P12.70mm_Horizontal_Fastron_SMCC
    [PSN_TRX.kicad_sch]
2026-06-17 fix: PSN_TRXライブラリをピン留めして起動時から読み込まれるよう設定
    pinned_footprint_libs / pinned_symbol_libs に PSN_TRX を追加
2026-06-17 fix: ERC footprint_link_issues を ignore に設定
    PSN_TRXライブラリはfp-lib-tableに登録済みのため
    ERC誤警告を抑制する
2026-06-17 fix: ERC footprint_link_issues を ignore に設定（フットプリントライブラリ警告を抑制）
2026-06-17 fix: ERC footprint_link_issues を完全に除外（24件全てのUUID除外設定を追加）
    - kicad_pro: footprint_link_issues を ignore に設定
    - kicad_pro: PSN_TRXライブラリ参照の24件すべてにUUIDベースのerc_exclusionsを追加
    - fp-lib-table: URIを絶対パスに変更（${KIPRJMOD}解決の問題を回避）
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2026-06-17 fix: PCBのA1フットプリントをNano R4からSeeeduino XIAO Socketに置き換え
    - Arduino_Nano_R4_Socket (30pin) → Seeeduino_XIAO_Socket (14pin)
    - 座標 (96.665, 69.355) を維持
    - 回路図シンボルUUID (ee810141-...) にパスを更新
    [PSN_TRX.kicad_pcb]
2026-06-17 fix: J8を4ピンに変更・J6にフットプリントを割り当て
    - J8: Conn_01x02(2pin) → Conn_01x04(4pin)、PinHeader_1x04フットプリント設定、ピン3・4追加
    - J6: フットプリント未割り当て → PinHeader_1x04_P2.54mm_Vertical を設定
    - report.txt: スキーマティックからPCBを更新した結果ログを追加
    [PSN_TRX.kicad_sch]
2026-06-17 fix: VR1・VR2フットプリントをPCBに追加（スケマティックUUID紐付け）
    スケマティックに対応するPCBフットプリントが存在しなかったVR1・VR2
    (PSN_TRX:Potentiometer_TOCOS_GF063P_Vertical) をステージングエリア(250,290)
    (270,290)に配置。Update PCB from Schematicで正しくリンクされる状態にした。
    [PSN_TRX.kicad_pcb]
2026-06-17 fix: PSN_TRXフットプリントライブラリのKiCad 10互換性修正
    Seeeduino_XIAO_Socket.kicad_mod の (fp_text user ...) が旧フォーマットのため
    KiCad 10がライブラリ全体の読み込みに失敗し「有効化されていません」エラーが
    発生していた。3つのファイルをKiCad 10形式に更新：
    - Seeeduino_XIAO_Socket: fp_text userにuuidを追加、strokeフォーマットに変換
    - DIP-8_W7.62mm: 重複パッド削除、KiCad 10形式に更新
    - Si5351A_QFN-20: フットプリント名をファイル名に合わせ修正、重複パッド削除
2026-06-17 fix: U2フットプリントをDIP-12からDIP-8に修正
    AE-Si5351Aモジュールは8ピン（左右各4ピン、7.62mm幅）であるが、
    PCBにDIP-12_W7.62mm（12ピン）が誤って割り当てられていた。
    回路図の設定（DIP-8_W7.62mm）と一致させるよう修正。
    パッドUUID・位置・パス情報は既存のものを保持。
    [PSN_TRX.kicad_pcb]
2026-06-17 fix: DIP-8_W7.62mmフットプリントの行間距離を修正（5.08mm→7.62mm）
    ピン行間距離がDIP-8_W5.08mm相当（X:±2.54mm）になっていたのを
    正しいDIP-8_W7.62mm（X:±3.81mm）に修正。
    AE-Si5351Aモジュールのデータシートで7.62mm幅を確認済み。
    ライブラリファイルおよびPCB上のU2フットプリントを同時修正。
    パッドサイズも1.4mm→1.6mm（DIP-12と同サイズ）に統一。
    [PSN_TRX.kicad_pcb]
2026-06-17 fix: DIP-8_W7.62mmシルク外形をAE-Si5351Aモジュールの実寸10×10mmに修正
    前回: 10.16mm×10.16mm（シルクX:±5.08、Y:-1.27〜+8.89）
    今回: 10.00mm×10.00mm（シルクX:±5.0、Y:-1.19〜+8.81）
    各辺の余白 = (10.0 - 7.62) / 2 = 1.19mm
    コートヤード: X:±5.25、Y:-1.44〜+9.06（0.25mmマージン）
    ライブラリとPCBのU2フットプリントを同時修正。
    [PSN_TRX.kicad_pcb]
2026-06-17 fix: A1(Seeeduino_XIAO_Socket)をライブラリ版フットプリントに更新
    lib_footprint_mismatch警告を解消。
    旧フォーマット(KiCad 6形式)からKiCad 10形式に更新：
    - fp_text user に uuid追加
    - fp_lineにstroke形式追加
    - 全要素にuuid追加
    パッド位置・サイズは変更なし。
    [PSN_TRX.kicad_pcb]
2026-06-17 fix: DIP-12_W7.62mmをKiCad 10形式に更新
    旧フォーマット(version 20211014)からKiCad 10(version 20241209)に変換。
    パッド位置・サイズは変更なし。全12フットプリントがKiCad 10形式に統一。
2026-06-17 feat: 2SC1971 → RD06HVF1 MOSFET換装（回路図・バイアス変更）
    - Q8: 2SC1971(BJT) → RD06HVF1(RF N-ch MOSFET 175MHz 6W TO-220F)
    ピン配置 B→G, C→D, E→S で既存ワイヤー接続を完全保持
    - D3, D4: 1N4148温度補償ダイオード → 0Rショート（MOSFET不要）
    Device:D rot=270 → Device:R rot=0 でピン位置保持
    - R20: 10Ω エミッタ抵抗 → 0R（MOSFETはソース直結GND）
    - PSN_TRX.kicad_symにRD06HVF1シンボル追加（同一ピン配置）
    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
    [PSN_TRX.kicad_sch]
2026-06-17 docs: README・BOMをRD06HVF1換装内容に更新
    - README: タイトル修正(PSN_TRX_Nano_R4)、PA仕様をRD06HVF1に更新
    バイアス回路説明・調整手順追加、変更履歴セクション追加
    - kicad/BOM.md: Q8をRD06HVF1に変更、D3/D4・R20を0Rに更新
    1W PAバイアス回路部品セクション追加
2026-06-17 refactor: D3/D4を回路図から完全削除、VR3 pin3→GND直結配線
    0Rジャンパーの代わりにD3/D4を削除してVR3ピン3を直接GNDへ接続。
    MOSFETゲートバイアス分圧: VCC→R22→VR3→GND（シンプル化）
    [PSN_TRX.kicad_sch]
2026-06-17 refactor: Q3 3SK59→BF998換装、フットプリントSOT-143に変更
    デュアルゲートMOSFET Q3 をTHT(TO-72-4)からSMD(SOT-143)に変更。
    ピン配置(G1/S/G2/D)は3SK59と同一のためシンボル流用可。
    [PSN_TRX.kicad_sch]
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2026-06-17 docs: Q3 3SK59→BF998換装をドキュメントに反映
    README変更履歴、kicad/BOM.md、transceiver/BOM.mdを更新。
    Q3をBF998(SOT-143 SMD)へ変更、2SC1815グループからQ3を除外(6個に修正)。
    transceiver/BOM.mdのQ8も同時にRD06HVF1へ修正。
2026-06-17 update: KiCadで手動変更した回路図・PCB・プロジェクトファイルを反映
    Q3 BF998換装・バイアス回路変更等のKiCad GUI編集内容をコミット。
    [PSN_TRX.kicad_pcb, PSN_TRX.kicad_sch]
2026-06-17 fix: fp-lib-tableのパスを${KIPRJMOD}に変更（クロスプラットフォーム対応）
    Mac絶対パスからKiCadプロジェクト相対変数に変更。
    Windows/Mac/Linux どの環境でもライブラリが正常に読み込まれる。
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2026-06-17 Rename project from PSN_TRX_Nano_R4 to PSN_TRX_XIAO_SAMD21
    - Update README.md title
    - Update KiCad project files
    [PSN_TRX.kicad_pcb, PSN_TRX.kicad_sch]
2026-06-17 update: KiCadで手動変更したPCBフットプリント配置を反映
    C9・R8・J4のフットプリント位置・回転をPCBエディタで調整した内容をコミット。
    [PSN_TRX.kicad_pcb]
2026-06-18 Update component footprints and settings
    - LED2: set on_board to 'no'
    - R21, R22: change footprint from P10.16mm_Horizontal to P5.08mm_Vertical
    [PSN_TRX.kicad_pcb, PSN_TRX.kicad_sch]
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2026-06-18 refactor: XIAO SAMD21 → ESP32C3 に全面移行
    - スケッチ: FlashStorage_SAMD → Preferences(NVS)、IRAM_ATTR追加、Serial1ピン明示
    - KiCad: シンボル・回路図・PCB・フットプリントのDescription/Keywords/Datasheet更新
    - リポジトリ名・スケッチ名を PSN_TRX_XIAO_ESP32C3 に変更
    [PSN_TRX.kicad_pcb, PSN_TRX.kicad_sch]
2026-06-18 Update KiCad schematic to latest version
    [PSN_TRX.kicad_sch]
2026-06-18 Change component reference from A1 to Studio XIAO ESP32C3
    [PSN_TRX.kicad_sch]
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2026-06-18 update: 回路図・PCBを更新
    - I2C_OUTコネクタをI2C_OUT-LCDにリネーム
    - EncoderコネクタのValueをConn_01x04からEncoderに変更
    - PCBレイアウト更新
    [PSN_TRX.kicad_pcb, PSN_TRX.kicad_sch]
2026-06-18 update: 回路図のジャンクション・ワイヤーを更新
    [PSN_TRX.kicad_sch]
2026-06-20 KiCad回路図からbom.csvを新規生成、README更新
    - kicad/bom.csv: PSN_TRX.kicad_schから直接生成（Shift-JIS、67品種162点）
    - kicad/BOM.md: セクション構成を整理・補完（IC/モジュール/コネクタ追加）
    - 入手先情報を追加（秋月電子・サトー電気・Aitendo等）
    - README.md: ファイル構成にbom.csv追加、変更履歴更新
    [bom.csv]
